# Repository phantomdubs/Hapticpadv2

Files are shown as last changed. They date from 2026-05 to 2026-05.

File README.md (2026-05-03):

# CNCDan - Haptic Pad
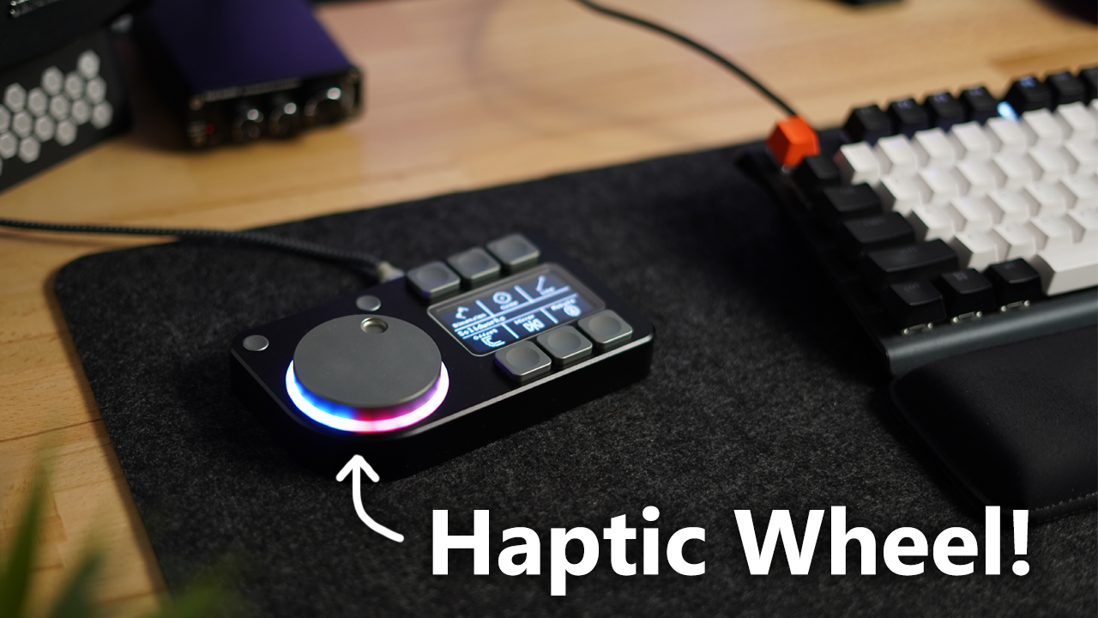
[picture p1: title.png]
Haptic Pad


A 6 button macropad with a display for button labels and a mouse knob with haptic feedback!

[Project Video Link](https://youtu.be/bNUKRJQjuvQ)

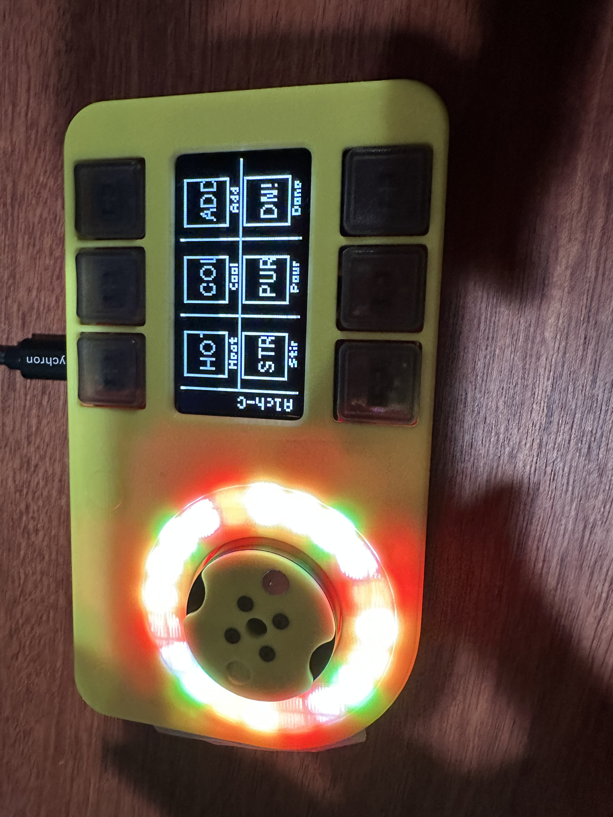
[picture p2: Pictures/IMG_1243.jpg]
Haptic Pad v2.0 Haptic Pad v2.0 Powered On


#### 🆕 New Advanced Features (v2.0)

*   **USB Drive Mode**: Edit your SD card files directly from your PC! Hold **Button 5 (Center Bottom)** while plugging in the USB cable to mount the internal SD card as a flash drive. 
*   **Reboot Shortcut**: While in USB Drive Mode, simply press **Button 1 (Top Left)** to exit and reboot the pad back into normal mode.
*   **Smart Sleep Mode**: To preserve the OLED display and save power, the pad automatically enters sleep mode after 5 minutes of inactivity. Press any button to wake it up.
*   **Per-Profile LEDs**: LED colors and modes are now tied to your active profile. Your pad can now automatically change its "look" whenever you switch between apps or games.
*   **Enhanced UI Layout**: The screen layout has been redesigned for better legibility. The profile name has been moved from the center to the edge of the screen, freeing up space for **larger 24x24 pixel icons** (upgraded from 16x16). 
*   **Diagnostic Tools**: Includes a `HardwareTester.uf2` file to quickly verify your wiring and motor directions before loading the main firmware.
*   **Custom Icon Support**: New Python scripts provided in the repository allow you to convert your own images into the exact bitmap format required for the OLED display. (**Note**: These scripts are intended as examples for icon creation and are not full-featured tools).

#### 🛠️ Design Improvements (v2.0)

The 3D files in this repository have been updated with several quality-of-life improvements:
*   **Choc Keycap Support**: The housing now features updated square keycap holes designed to fit standard **Kailh Choc low-profile keycaps** (available on Amazon/AliExpress) instead of being limited to custom 3D printed ones.
*   **Pico Button Access**: The bottom plate now includes two access holes so you can press the physical **Boot** and **Reset** buttons on the RP2040-Plus board without disassembling the case.
*   **Better Magnet Fit**: Magnet pockets on the knob and the knob interface plate have been slightly enlarged for a much better "press-fit" experience.

> [!IMPORTANT]
> **Assembly Note**: If you are using standard Choc keycaps, the **bottom-center keycap** must be trimmed down on its underside. This is necessary to prevent it from interfering with or damaging the LCD screen's ribbon cable during use.

#### 💡 Technical Notes & Troubleshooting

*   **Display Stability**: It is highly recommended to install the **10nF capacitor** (C1) on the controller board. This was optional in earlier versions but has been found necessary to reduce noise and prevent display flickering.
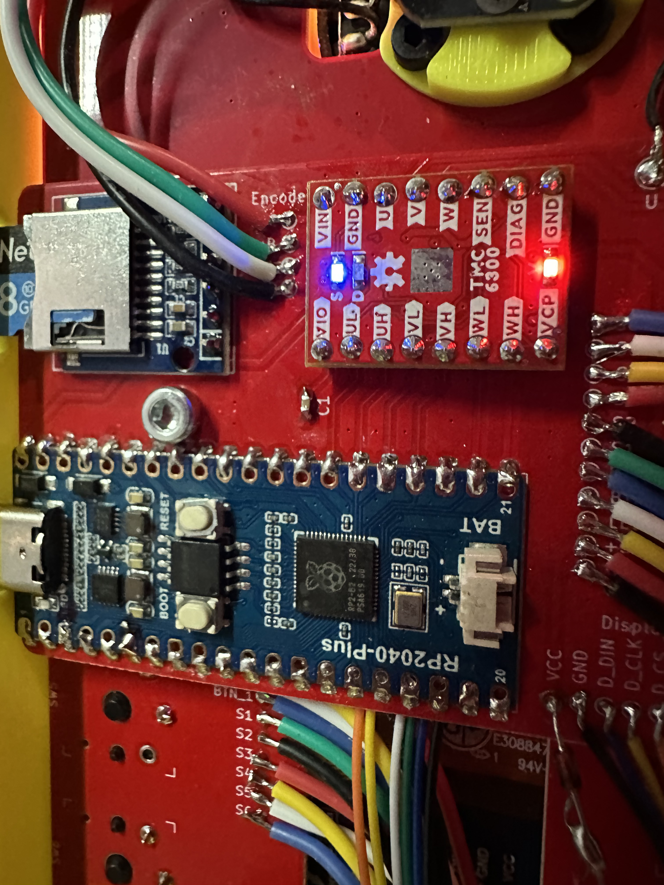
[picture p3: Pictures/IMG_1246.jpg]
Capacitor C1 Location Capacitor C1 on RP2040-Plus
    
*   **Voltage Logic Fix**: While the OLED display is rated for 5V, it can behave erratically when receiving 3.3V logic signals from the Pico. To fix this, **add a diode inline** with the 5V power supply to the display. This drops the voltage to ~4V, allowing the 3.3V logic signals to communicate reliably with the display.
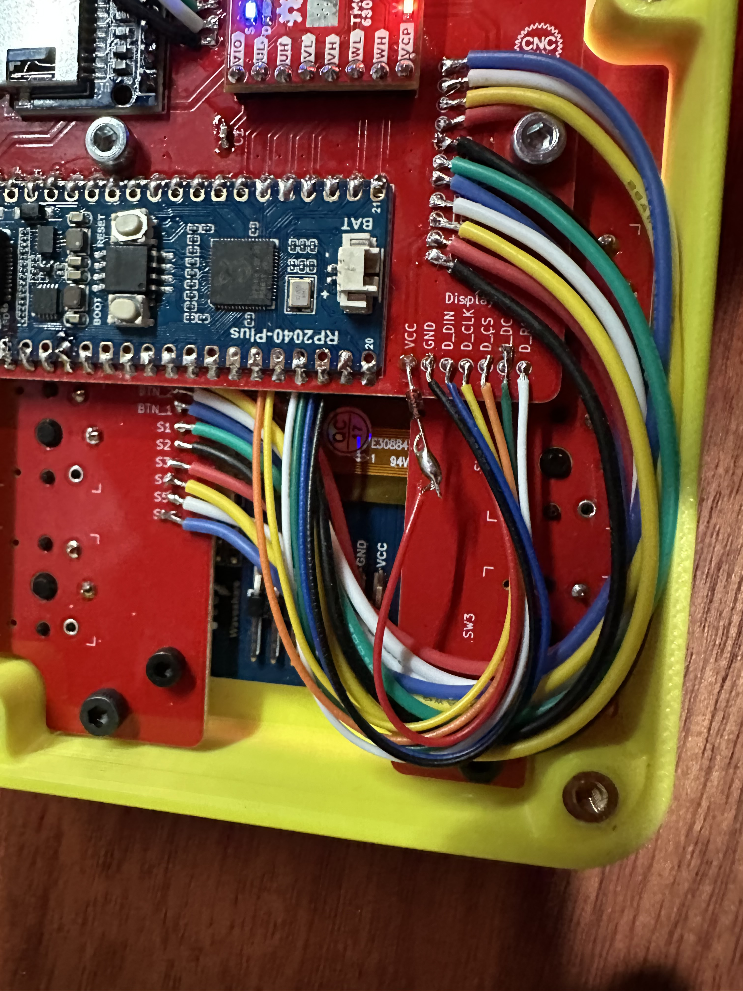
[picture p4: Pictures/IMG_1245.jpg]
Inline Diode Fix Inline Diode for Voltage Drop
    
*   **Hardware Tester Bug**: When running the knob test in `HardwareTester.uf2`, the mode names displayed on the screen (Clicky, Twist, Momentum) may not match the actual haptic mode being tested. As long as you feel three distinct haptic behaviors as you cycle through, your motor and encoder are working correctly.

#### Bill of Materials

For a complete list of components and purchasing links, please refer to the **[Parts List.csv](Parts%20List.csv)** file included in the root of this repository.

#### Printing Instructions

#### - Printed version
Print all files in the **3D Files/STL's** folder. You will need:
*   6 of the keycap file (**Note**: Only required if you are NOT using the updated v2.0 housing).
*   Two of the Menu button file.
*   Two of the PCB spacer file.

#### - Machined Version
Print all files in the **3D Files/STL's** folder except: "Custom Keycap.STL", "Macro Pad - Printed Version.STL" and "Menu Button Printed.STL".
Get all of the .STEP files in the **3D Files/STEP** folder machined. Don't include the Macropad Assembly .STEP file from the main directory as it is a complete model of Macro Pad rather than an individual part.

---

### Software

> [!TIP]
> **Recommended First Step**: Flash the `HardwareTester.uf2` file found in the `HardwareTester` folder first. This allows you to verify all your buttons, the display, and the motor encoder are working correctly before loading the full MacroPad firmware.

#### Flashing the Firmware
If you don't wish to compile the code yourself, just copy the latest version of the `MacroPad_V2.0.uf2` file from the software folder and install it directly onto the memory of your Pico using the boot method shown in the video.

You will also need to have your SD card set up correctly in order to use the macro pad.
Copy the entire contents of the **Example SD Card** folder onto you SD card to begin with. This folder now includes **6 extensive example profiles** (`StarNavC`, `Mech-T`, `CybMix-M`, `Alch-C`, `Hack-T`, and `Race-M`) to help you get started.

### XML Config

In the `<Settings>` tag of the XML file you will find the P and I tuning values for the various wheel modes.

#### Per-Profile Settings
Unlike previous versions, the LED settings are now stored **inside each profile**. This allows you to have unique lighting for every application.

*   `<LED_Mode>`: Acceptable inputs are `Breath`, `Bands`, `Halo`, `Rainbow`, `Solid`, and `Off`.
*   `<LED_Primary>` & `<LED_Secondary>`: Colors formatted as R,G,B (0-255). 
*   `<LED_Brightness>`: Set the intensity (0-255).
*   `<WheelMode>`: `Clicky`, `Twist`, or `Momentum`.
*   `<WheelKey>`: Any key value from [keycode-visualizer](https://keycode-visualizer.netlify.app/) to be held while the wheel is moving.

#### Macro Buttons
Each profile contains 6 `<MacroButton>` tags:
```xml
<MacroButton>
    <Action>0,68</Action> <!-- Delay(ms), KeyCode -->
    <Action>0,0</Action>
    <Action>0,0</Action>
    <Label>Dimension</Label>
</MacroButton>
```
Each action has two values: the delay (in ms) followed by the keycode. Setting both to 0 skips the action.

---

### Hardware Assembly & PCB's

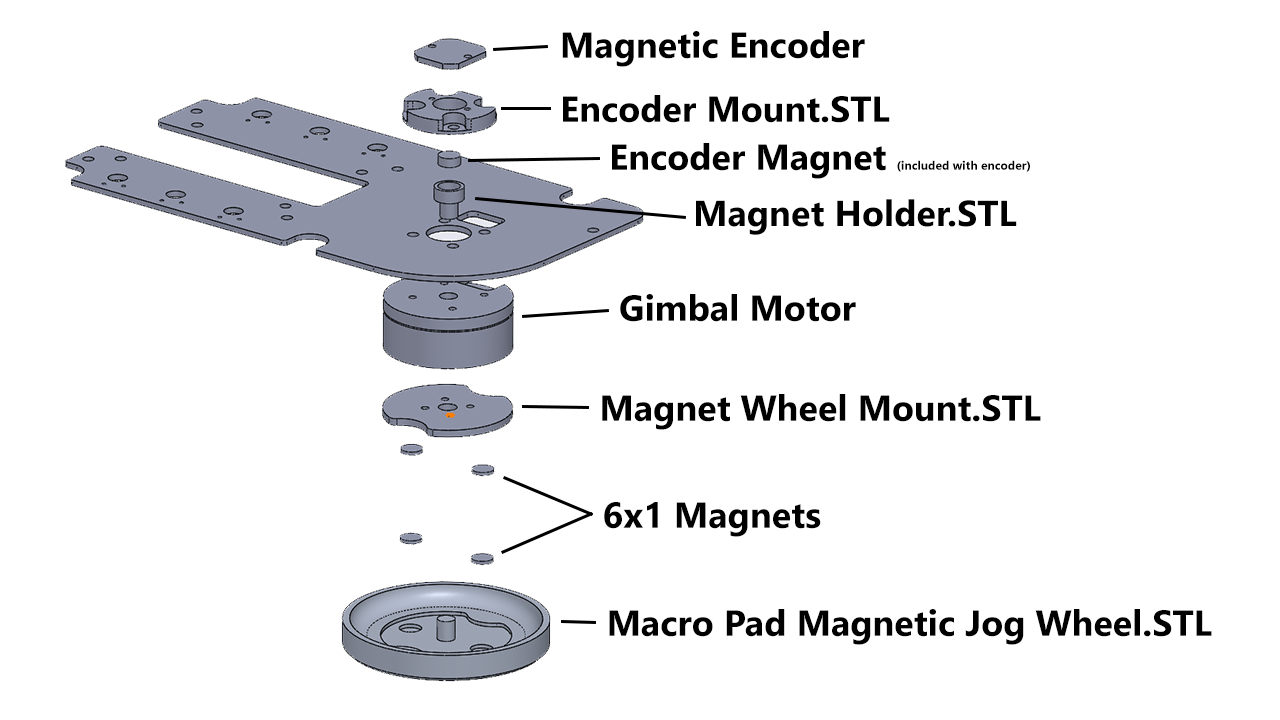
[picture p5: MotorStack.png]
Exploded Motor Assembly Motor Stack Assembly Diagram


*(See the original repository for detailed wiring diagrams and PCB assembly guides)*

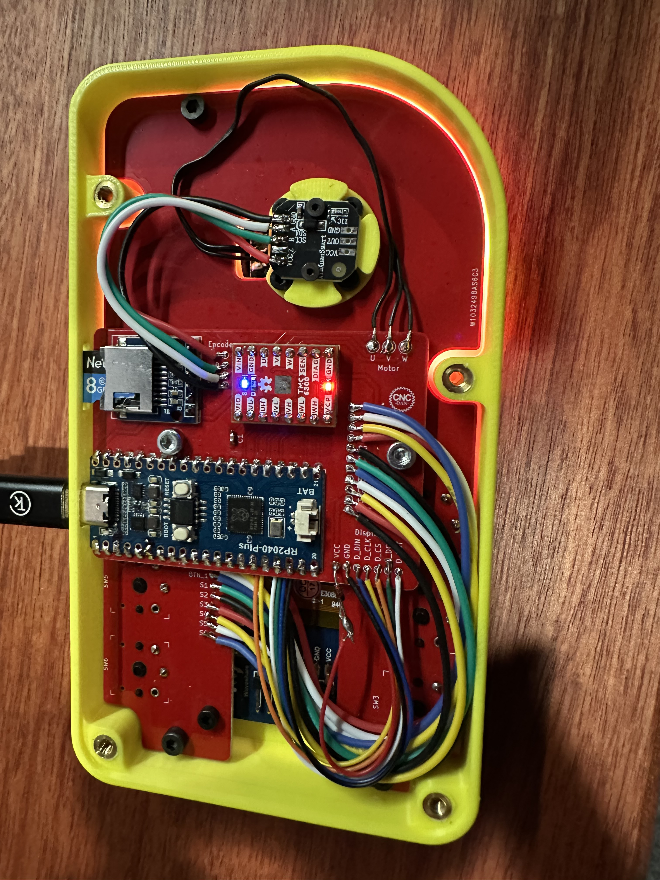
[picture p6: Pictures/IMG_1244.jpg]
Assembled Internal Wiring Internal Wiring View

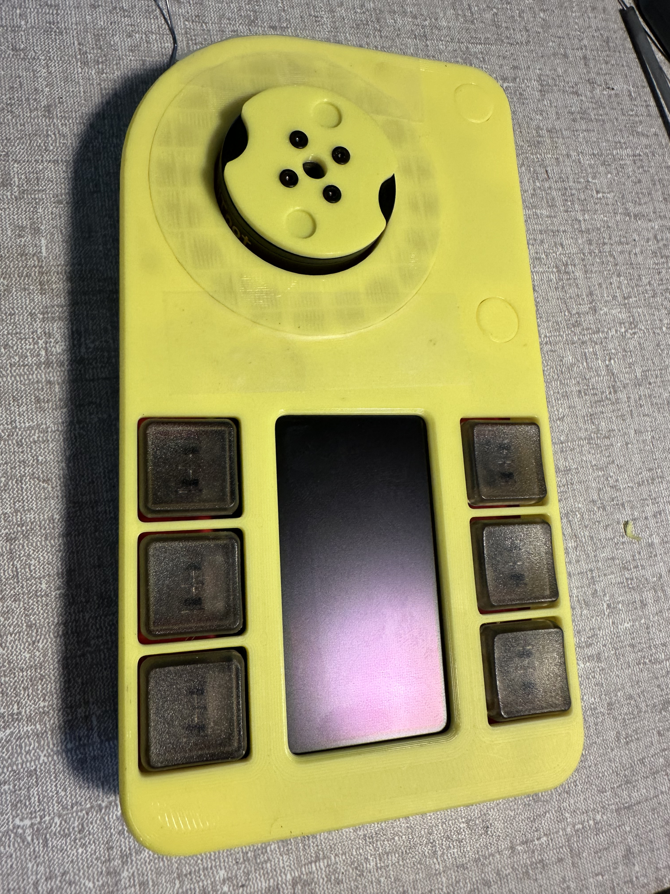
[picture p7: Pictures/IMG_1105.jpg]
Assembled Top View Haptic Pad Assembled (Top)


You will need to have both PCB's made to complete this project. Zip files for manufacturing can be found in `PCB's/MacroPad` and `PCB's/MacroPad Controller Board`.

**Controller Board**: The SD reader should be flat against the PCB. The motor controller gets installed on pin headers with the "bottom" face up. The Pico should be soldered directly with its USB port facing outwards.

**Main Board**: If including LEDs, install them first! Match the arrow rebate to the "1" pad. All "C" components are 0.1uF 0603 capacitors.

**Connecting**: Boards are connected via direct wiring. Match the labels on both boards. The three motor wires connect to U, V, and W (order can be swapped if direction is wrong). Encoder connections are also labelled—only the four main pins are required.

> [!TIP]
> **Screw Installation Hack**: The original design calls for tapping the plastic for M2 screws. If you don't have an M2 tap, you can simply use a hot soldering iron to carefully press the screws into the pre-sized holes in the plastic. This melts the plastic slightly around the threads, creating a very secure hold once cooled.

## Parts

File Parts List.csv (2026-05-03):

Part Name | PN (if available) | QTY Reqd | price | qty designator | link
128x64 OLED Display | sku: 25742 | 1 | $12.99 | ea | https://www.waveshare.com/2.42inch-oled-module.htm
Magnetic Encoder Board (mt6701) | MT6701 | 1 | $4.12 | ea | https://www.aliexpress.com/item/1005007469177411.html
2804 100kv Brushless Gimbal Motor | 2804 100kv | 1 | $23.44 | ea | https://www.aliexpress.us/item/3256801872144034.html?curPageLogUid=ZmV0swoLEkdW
Kailh Low Profile Switches | 1350 | 1 | $12.20 | 30 pack | https://www.aliexpress.us/item/3256804880270570.html?gatewayAdapt=glo2usa4itemAdapt
RP2040-Plus Board (without header) | RP2040-Plus-16MB | 1 | $6.99 | ea | https://www.waveshare.com/rp2040-plus.htm?sku=23503
TMC6300 Motor Driver Board | TMC6300 | 1 | $17.95 | ea | https://www.sparkfun.com/sparkfun-brushless-motor-driver-3-phase-tmc6300.html
Micro SD Module-3.3V SPI TF Storage |  | 1 | $0.99 | 10 pk | https://www.aliexpress.us/item/3256810401669594.html?gatewayAdapt=glo2usa4itemAdapt
6x1mm Magnets |  | 1 | $2.53 | 50 pk | https://www.aliexpress.us/item/3256809708457389.html?gatewayAdapt=glo2usa4itemAdapt
Tactile Buttons | EVQ-Q2B03W | 1 | $2.26 | 10 pk | https://www.digikey.com/en/products/detail/panasonic-electronic-components/EVQ-Q2B03W/762882
Alternate Tactile Button | Order 3.1 height | 1 | 3.20 | 30 pk | https://www.aliexpress.us/item/3256808139893877.html
WS2811 LED's | WS2811 | 1 | $10.08 | 200 pk | https://www.aliexpress.us/item/2251832590417125.html?gatewayAdapt=glo2usa4itemAdapt
0.1uF (100nF) 0603 Capacitors |  | 1 | $1.52 | 100 pk | https://www.aliexpress.us/item/2251832780211793.html?gatewayAdapt=glo2usa4itemAdapt
Large PCB |  | 1 | $29.35 | 5 pk | Pcbway
Small PCB |  | 1 | $5.00 | 5 pk | pcbway
M3x5x5 Threaded Inserts | 94180A331 | 2 | $7.27 | pk 25 | McMaster carr
M3x6 SHCS | 91290A111 | 1 | $11.59 | pk 100 | McMaster carr
M3x10 SHCS | 95263A134 | 1 | $8.55 | pk 50 | McMaster carr
M2.5x4 SHCS | 91290A099 | 1 | $12.44 | pk 50 | McMaster carr
M3x6 CSK | 91294A126 | 1 | $5.45 | pk 100 | McMaster carr
Low profile keycaps |  | 1 | 13.99 | Pk 20 | https://www.amazon.com/dp/B0FK283QCB?th=1
M2-.04x6mm fhshcs |  | 1 | 6.79 | Pk 50 | https://www.amazon.com/dp/B0CQ1KS9NJ?th=1
Switching Signal Diode 200 mA 100 V Axial 100 Volt | 1N4148 DO-35 | 1 | 3.79 | Pk 20 | https://www.amazon.com/dp/B0DS1JLQ1X?th=1
Assorted Capacitors (to get 10nF) |  | 1 | 7.98 | Multi pack | https://www.amazon.com/dp/B06XDG3WQX?

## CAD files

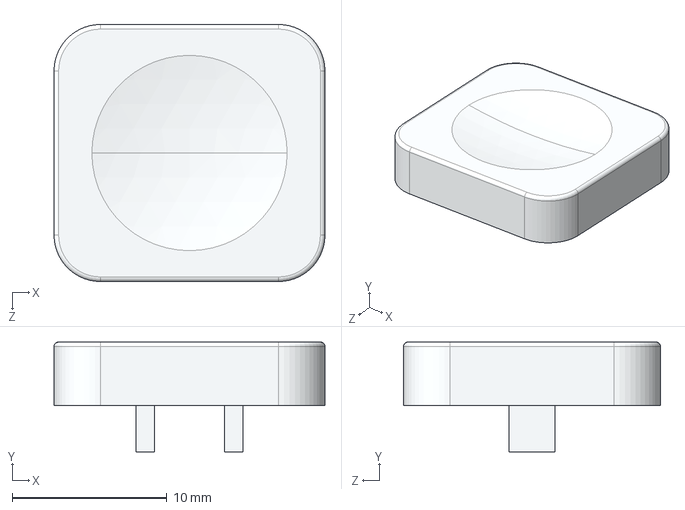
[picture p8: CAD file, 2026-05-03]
3D Files/STEP/Custom Keycap - Machined.STEP
17.5 x 7.10 x 16.6 mm

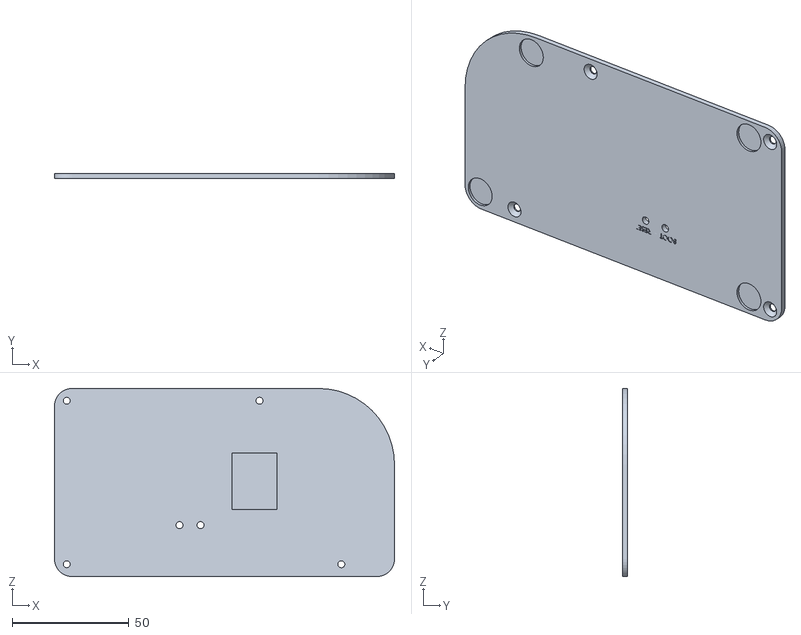
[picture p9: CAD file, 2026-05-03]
3D Files/STL's/Macropad Bottom Cover WITH reset and boot HOLES.STL
145.5 x 2.00 x 80.5

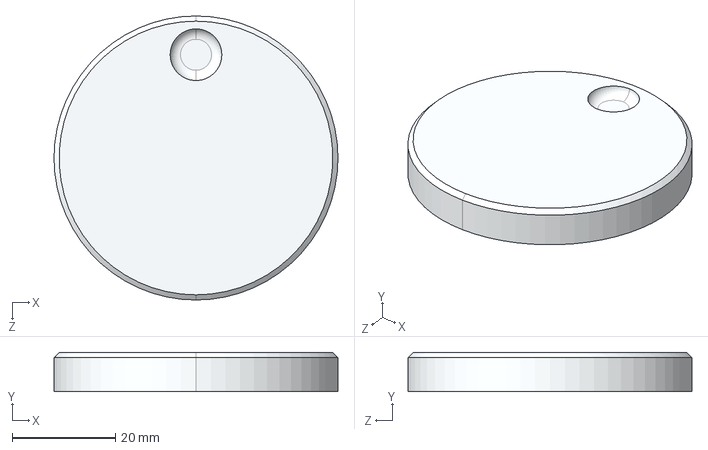
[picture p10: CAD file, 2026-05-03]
3D Files/STEP/Macro Pad Jog Wheel Machined.STEP
55.0 x 7.60 x 55.0 mm

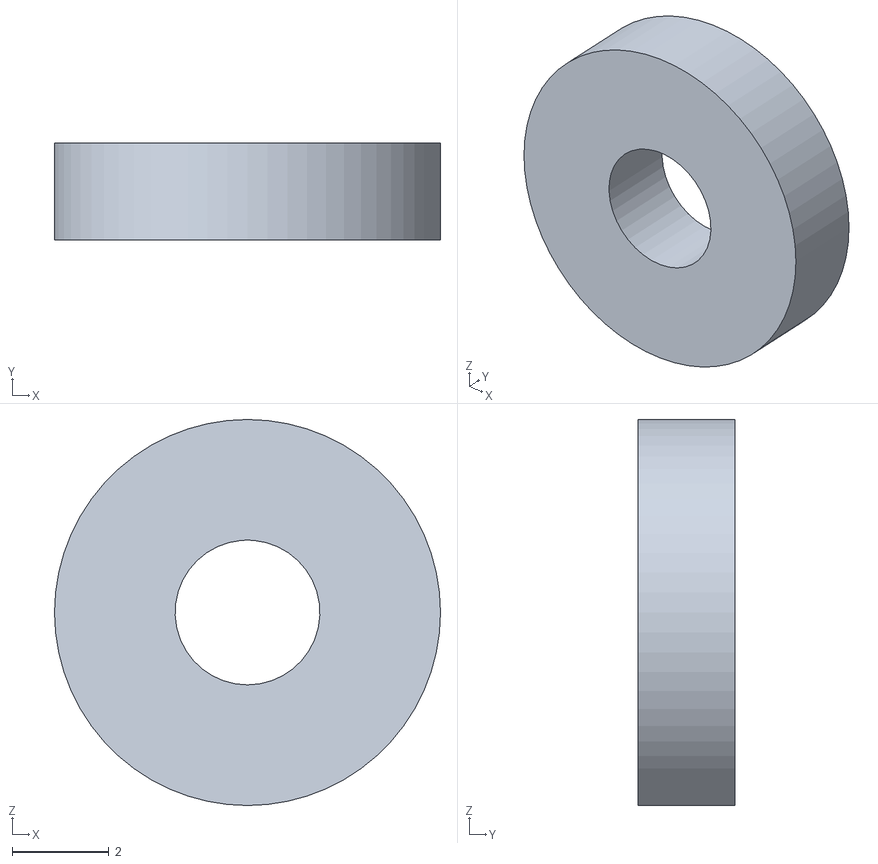
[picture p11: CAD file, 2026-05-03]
3D Files/STL's/PCB Spacer.STL
8.00 x 2.00 x 8.00

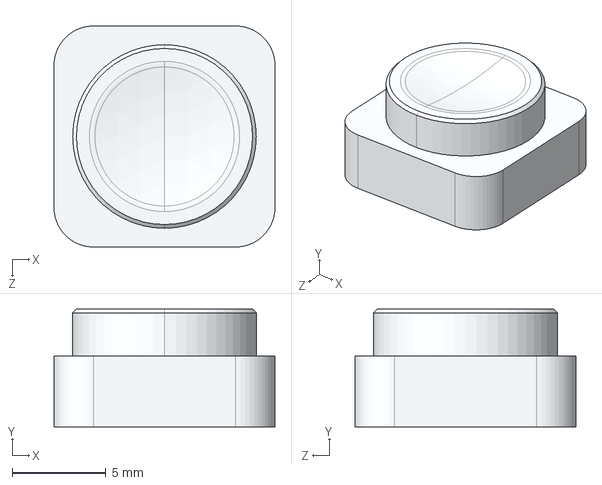
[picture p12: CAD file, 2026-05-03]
3D Files/STEP/Menu Button - Machined.STEP
11.8 x 6.30 x 11.8 mm

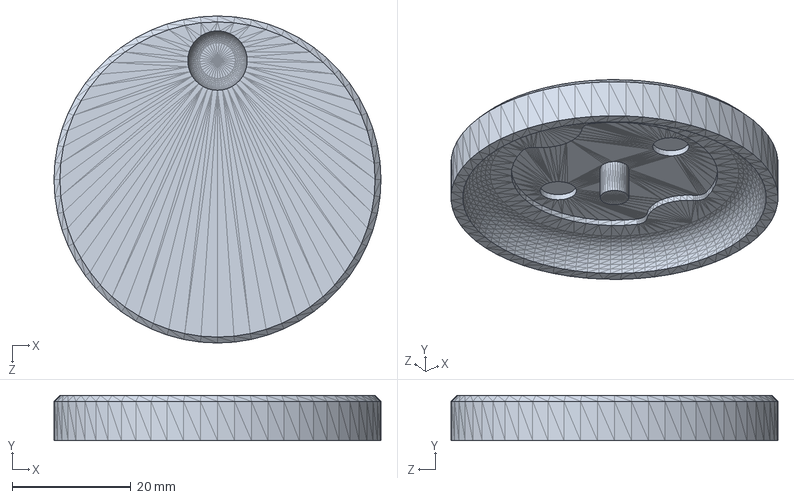
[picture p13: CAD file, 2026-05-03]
3D Files/STL's/Macro Pad Magnetic Jog Wheel 4-24-26.SLDPRT
55.0 x 7.60 x 55.0 mm

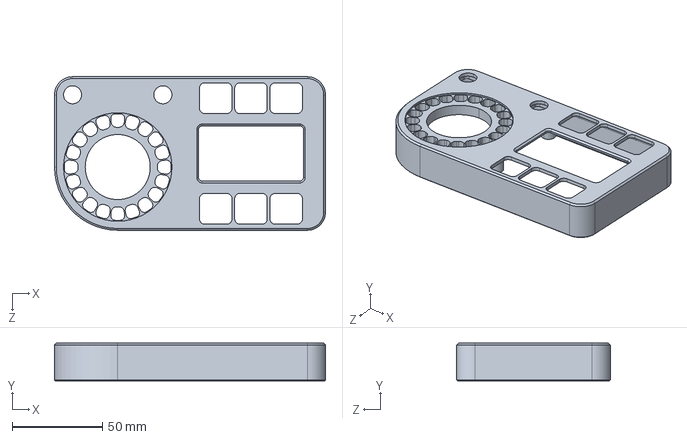
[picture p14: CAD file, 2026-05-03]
3D Files/STEP/Macro Pad Machined.STEP
150.0 x 21.0 x 85.0 mm

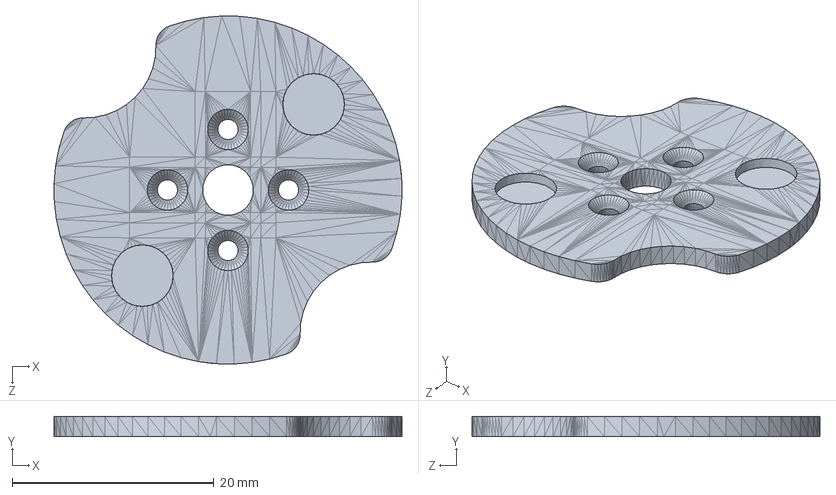
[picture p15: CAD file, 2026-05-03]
3D Files/STL's/Magnet Wheel Mount 4-24-26.SLDPRT
34.5 x 2.00 x 34.5 mm

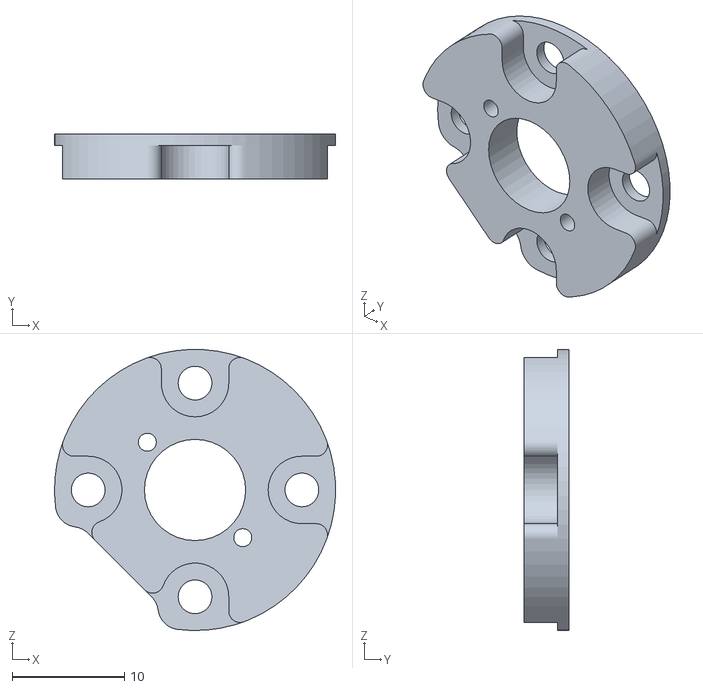
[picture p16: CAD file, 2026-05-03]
3D Files/STL's/Encoder Mount.STL
25.0 x 4.00 x 25.0

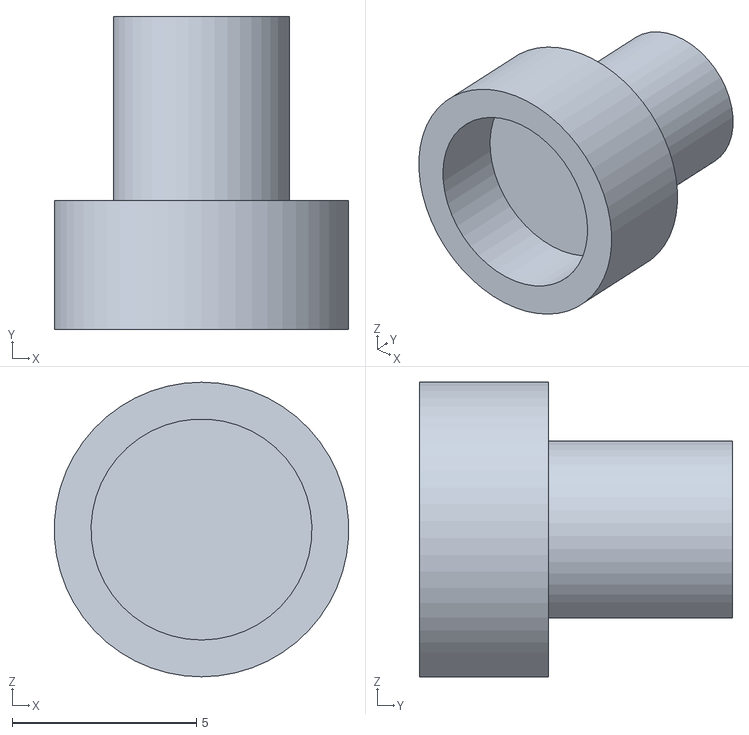
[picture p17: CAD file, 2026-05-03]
3D Files/STL's/Magnet Holder.STL
7.99 x 8.50 x 8.00

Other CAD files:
3D Files/STL's/Menu Button Printed.STL
3D Files/STL's/Macro Pad Magnetic Jog Wheel enlarged magnet 4-24-26.STL
3D Files/STL's/Custom Keycap.STL
3D Files/STL's/Macropad Bottom Cover.STL
3D Files/STL's/Magnet Wheel Mount.STL
3D Files/STL's/Macro Pad - Purchased Keycaps Revision Printed Version.STL
3D Files/STL's/Macro Pad - Printed Version.SLDPRT
3D Files/STL's/Macro Pad Magnetic Jog Wheel.STL
3D Files/STL's/LED Diffuser Ring.STL
3D Files/STL's/Macro Pad - Printed Version.STL
3D Files/STL's/Magnet Wheel Mount enlarged magnet 4-24-26.STL

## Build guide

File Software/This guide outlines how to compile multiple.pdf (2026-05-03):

This guide outlines how to compile multiple .ino files into a single .uf2 binary using the Arduino IDE. This process is common for modern microcontrollers like the Raspberry Pi Pico (RP2040) or ESP32-S2/S3.

Phase 1: Preparation & Organization
The Arduino IDE treats multiple files as a single project "sketch".
1. | 1. | Folder Setup: Place all six .ino files in a single folder. The folder name
must match the name of the main .ino file.
2. | 2. | Tab Order: Open the main .ino file. The other files will automatically
appear as tabs at the top.
- | o | Logic: The IDE concatenates (merges) these tabs into one large file
behind the scenes.
- | o | Sequence: It starts with the main file and then appends the others
in alphabetical order.
- | o | Tip: To control the merge order, rename tabs with a numeric prefix
(e.g., 10_Global.ino, 20_Setup.ino).

Phase 2: Compiling to Binary
Standard "Uploading" via the arrow button often bypasses the creation of a permanent file you can save. To get a file you can drag-and-drop, use the Export feature.
1. | 1. | Select Board: Go to Tools > Board and select your specific device.
2. | 2. | Verify Code: Click the Checkmark (Verify) icon to ensure no errors exist
in any tab.
3. | 3. | Export: Select Sketch > Export Compiled Binary.
- | o | This creates a subfolder in your project directory (usually called
build).
- | o | Depending on your board, this folder will contain .bin, .elf,
or .hex files.

NEW NOTE: Use save as function to start on a new revision and it will create the necessary adjustments

NEW NOTE: Use save as function to start on a new revision and it will create the necessary adjustmentsNOTES: after exporting it creates the build folder which has some subfolders and includes the UF2 file that is uploaded to the device. If you want to make a modification you need to dump everything into a new base folder or rename the existing build folder so it doesn’t get overwritten

Phase 3: Converting to UF2
A .uf2 file is specifically designed for "USB Flashing." Not all board packages generate this automatically.
Option A: Automatic Generation (Easiest)
Many modern board packages (like the Raspberry Pi Pico Mbed or Earle Philhower cores) automatically create a .uf2 file in the build folder alongside the other binaries when you click "Export Compiled Binary".
Option B: Using a Converter Tool
If the IDE only gives you a .bin or .hex file, you need a utility to convert it.
- | • | Utility Needed: uf2conv.py (a Python script provided by Microsoft/
Adafruit).
- | • | Step-by-Step:
1. | 1. | Install Python 3 on your computer.
2. | 2. | Open a Terminal or Command Prompt in the folder containing
your binary.
3. | 3. | Run the command:
python uf2conv.py firmware.bin -c -f [FamilyID]
(Replace firmware.bin with your file name. The "FamilyID" for RP2040 is
0xe48bff57).

Phase 4: Flashing the Device
1. | 1. | Enter Bootloader Mode: Plug in your device while holding its BOOT or
RESET button.
2. | 2. | Mount Drive: A new drive will appear on your computer (e.g., RPI-RP2
or CPLAYBOOT).
3. | 3. | Deploy: Drag your .uf2 file and drop it onto that drive.
4. | 4. | Auto-Run: The drive will disappear, and the device will reboot
automatically with your new code.
Summary Checklist
- | • | Software: Arduino IDE.
- | • | Utility: Python 3 (for manual conversion).
- | • | Key Command: Sketch > Export Compiled Binary.
- | • | File Location: Found via Sketch > Show Sketch Folder.

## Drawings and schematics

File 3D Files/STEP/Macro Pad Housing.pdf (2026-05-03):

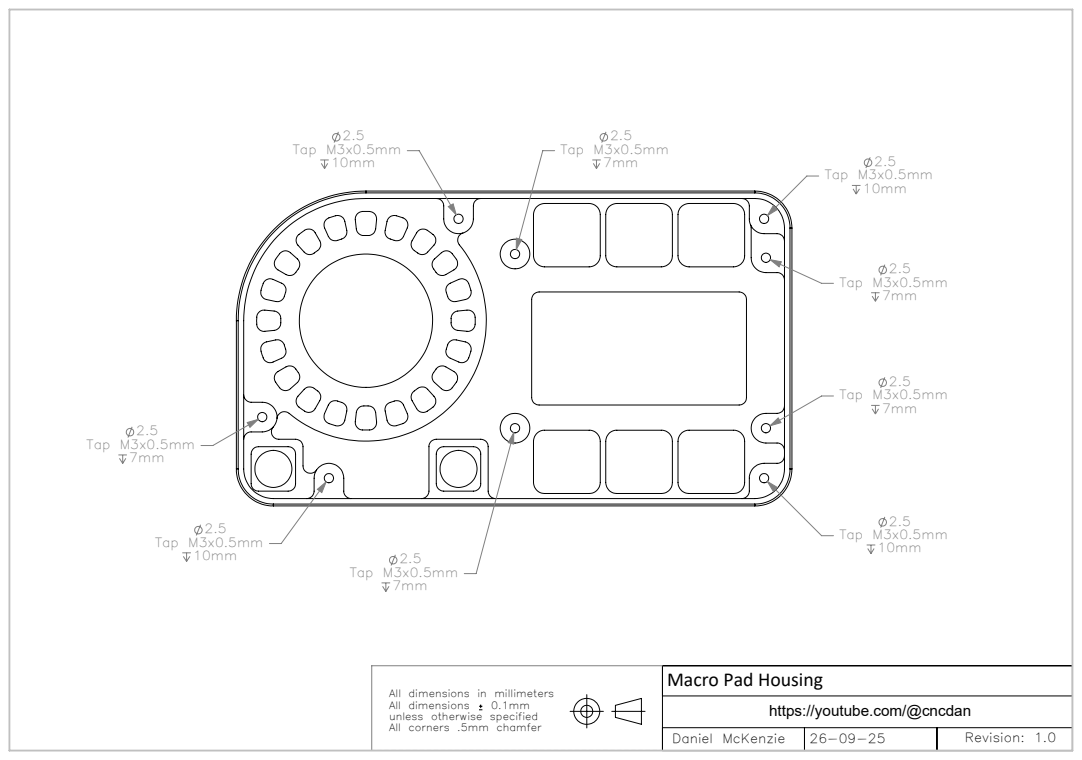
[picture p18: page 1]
Tap M3x0.5mm; Daniel McKenzie; Revision: 1.0; All dimensions

Macro Pad Housing

All dimensions in millimeters
unless otherwise specified
All corners .5mm chamfer

https://youtube.com/@cncdan

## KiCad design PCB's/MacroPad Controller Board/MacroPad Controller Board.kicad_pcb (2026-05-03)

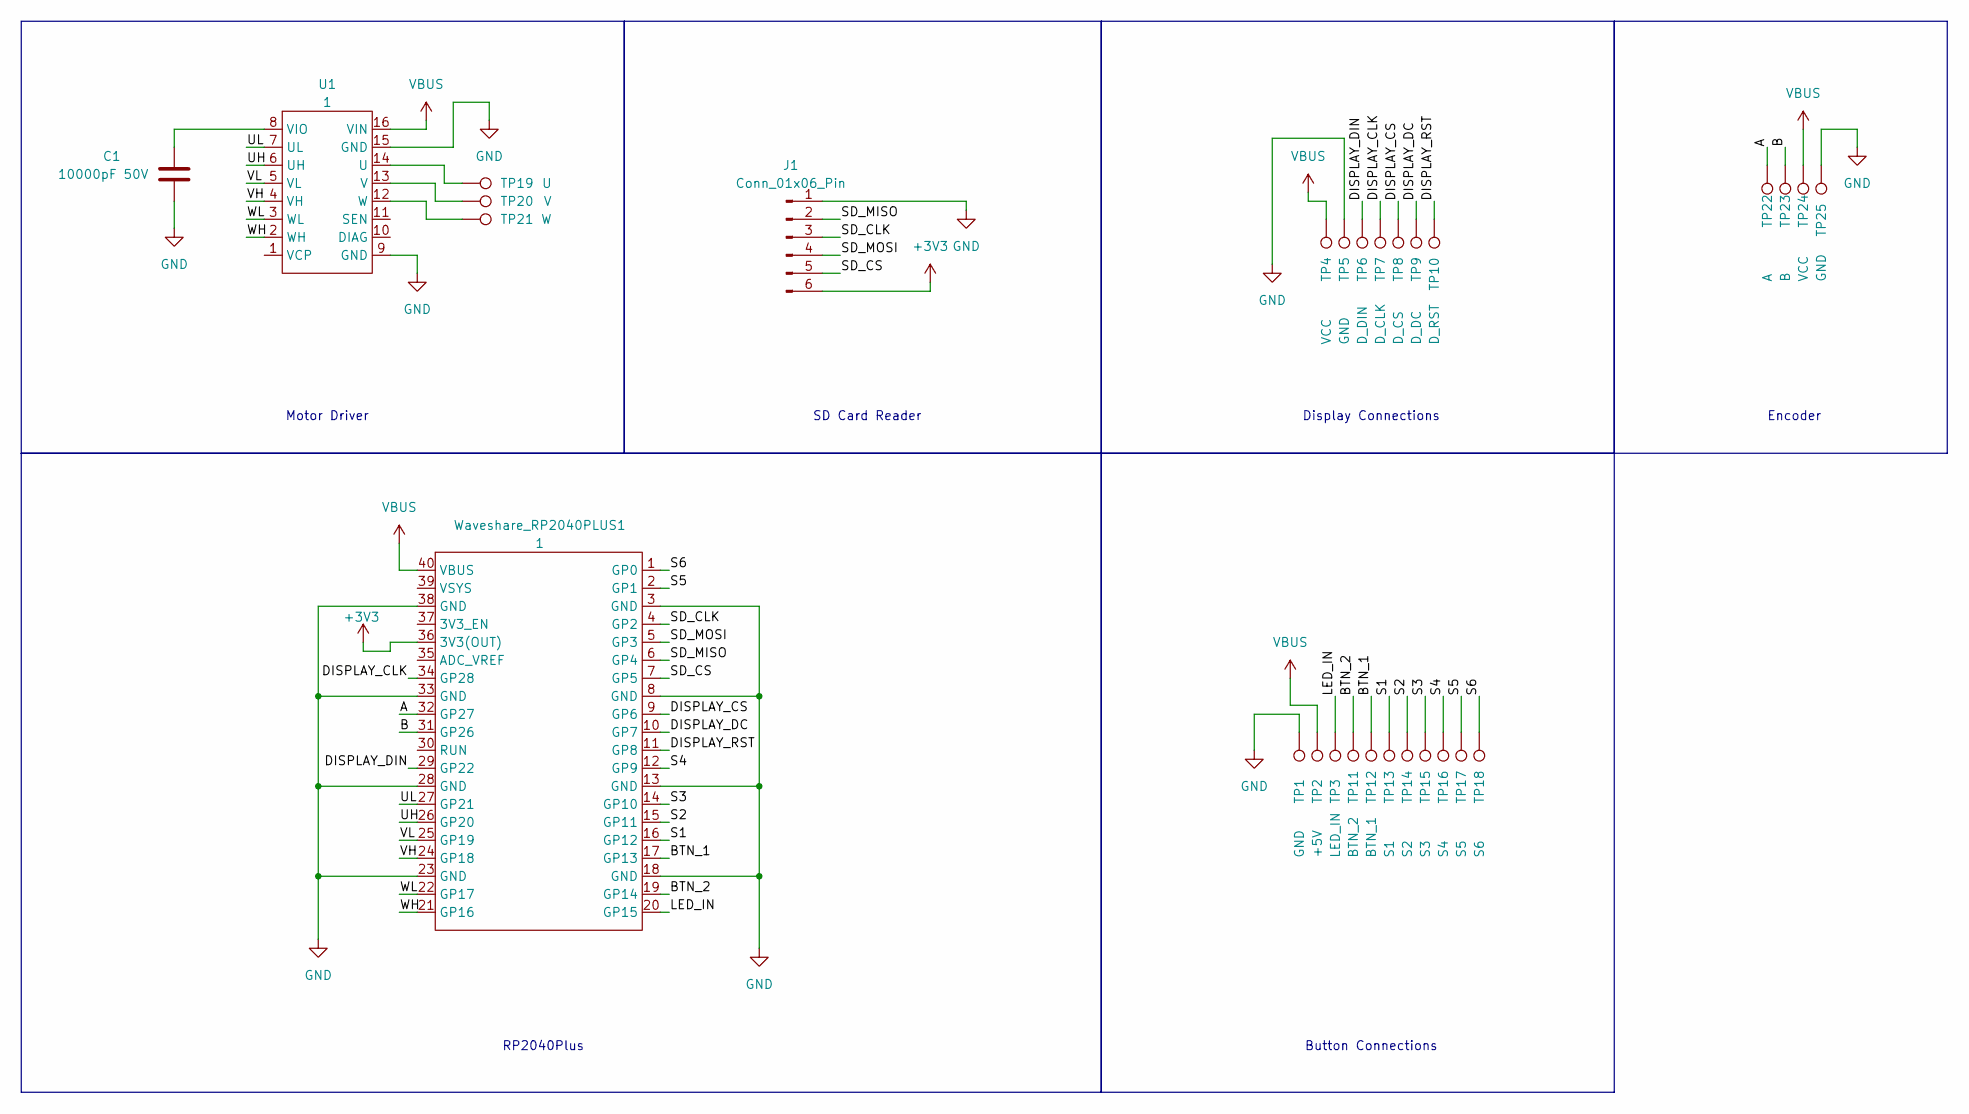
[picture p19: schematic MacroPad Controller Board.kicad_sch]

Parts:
C1: 10000pF 50V; C_0603_1608Metric_Pad1.08x0.95mm_HandSolder
J1: Conn_01x06_Pin; PinHeader_1x06_P2.54mm_Vertical
TP1, TP5, TP25: GND; TestPoint_THTPad_D1.0mm_Drill0.5mm
TP2: +5V; TestPoint_THTPad_D1.0mm_Drill0.5mm
TP3: LED_IN; TestPoint_THTPad_D1.0mm_Drill0.5mm
TP4, TP24: VCC; TestPoint_THTPad_D1.0mm_Drill0.5mm
TP6: D_DIN; TestPoint_THTPad_D1.0mm_Drill0.5mm
TP7: D_CLK; TestPoint_THTPad_D1.0mm_Drill0.5mm
TP8: D_CS; TestPoint_THTPad_D1.0mm_Drill0.5mm
TP9: D_DC; TestPoint_THTPad_D1.0mm_Drill0.5mm
TP10: D_RST; TestPoint_THTPad_D1.0mm_Drill0.5mm
TP11: BTN_2; TestPoint_THTPad_D1.0mm_Drill0.5mm
TP12: BTN_1; TestPoint_THTPad_D1.0mm_Drill0.5mm
TP13: S1; TestPoint_THTPad_D1.0mm_Drill0.5mm
TP14: S2; TestPoint_THTPad_D1.0mm_Drill0.5mm
TP15: S3; TestPoint_THTPad_D1.0mm_Drill0.5mm
TP16: S4; TestPoint_THTPad_D1.0mm_Drill0.5mm
TP17: S5; TestPoint_THTPad_D1.0mm_Drill0.5mm
TP18: S6; TestPoint_THTPad_D1.0mm_Drill0.5mm
TP19: U; TestPoint_THTPad_D2.0mm_Drill1.0mm
TP20: V; TestPoint_THTPad_D2.0mm_Drill1.0mm
TP21: W; TestPoint_THTPad_D2.0mm_Drill1.0mm
TP22: A; TestPoint_THTPad_D1.0mm_Drill0.5mm
TP23: B; TestPoint_THTPad_D1.0mm_Drill0.5mm
U1: 1; Sparkfun_TMC6300
Waveshare_RP2040PLUS1: 1; RP2040PLUS_SMD

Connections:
+3V3: J1.6, Waveshare_RP2040PLUS1.36 (3V3(OUT)); also elsewhere on the board
/A: TP22.1, Waveshare_RP2040PLUS1.32 (GP27); also elsewhere on the board
/B: TP23.1, Waveshare_RP2040PLUS1.31 (GP26); also elsewhere on the board
/BTN_1: TP12.1, Waveshare_RP2040PLUS1.17 (GP13); also elsewhere on the board
/BTN_2: TP11.1, Waveshare_RP2040PLUS1.19 (GP14); also elsewhere on the board
/DISPLAY_CLK: TP7.1, Waveshare_RP2040PLUS1.34 (GP28); also elsewhere on the board
/DISPLAY_CS: TP8.1, Waveshare_RP2040PLUS1.9 (GP6); also elsewhere on the board
/DISPLAY_DC: TP9.1, Waveshare_RP2040PLUS1.10 (GP7); also elsewhere on the board
/DISPLAY_DIN: TP6.1, Waveshare_RP2040PLUS1.29 (GP22); also elsewhere on the board
/DISPLAY_RST: TP10.1, Waveshare_RP2040PLUS1.11 (GP8); also elsewhere on the board
/LED_IN: TP3.1, Waveshare_RP2040PLUS1.20 (GP15); also elsewhere on the board
/S1: TP13.1, Waveshare_RP2040PLUS1.16 (GP12); also elsewhere on the board
/S2: TP14.1, Waveshare_RP2040PLUS1.15 (GP11); also elsewhere on the board
/S3: TP15.1, Waveshare_RP2040PLUS1.14 (GP10); also elsewhere on the board
/S4: TP16.1, Waveshare_RP2040PLUS1.12 (GP9); also elsewhere on the board
/S5: TP17.1, Waveshare_RP2040PLUS1.2 (GP1); also elsewhere on the board
/S6: TP18.1, Waveshare_RP2040PLUS1.1 (GP0); also elsewhere on the board
/SD_CLK: J1.3, Waveshare_RP2040PLUS1.4 (GP2); also elsewhere on the board
/SD_CS: J1.5, Waveshare_RP2040PLUS1.7 (GP5); also elsewhere on the board
/SD_MISO: J1.2, Waveshare_RP2040PLUS1.6 (GP4); also elsewhere on the board
/SD_MOSI: J1.4, Waveshare_RP2040PLUS1.5 (GP3); also elsewhere on the board
/UH: U1.6 (UH), Waveshare_RP2040PLUS1.26 (GP20); also elsewhere on the board
/UL: U1.7 (UL), Waveshare_RP2040PLUS1.27 (GP21); also elsewhere on the board
/VH: U1.4 (VH), Waveshare_RP2040PLUS1.24 (GP18); also elsewhere on the board
/VL: U1.5 (VL), Waveshare_RP2040PLUS1.25 (GP19); also elsewhere on the board
/WH: U1.2 (WH), Waveshare_RP2040PLUS1.21 (GP16); also elsewhere on the board
/WL: U1.3 (WL), Waveshare_RP2040PLUS1.22 (GP17); also elsewhere on the board
GND: C1.2, J1.1, TP1.1, TP5.1, TP25.1, U1.9 (GND), U1.15 (GND), Waveshare_RP2040PLUS1.3 (GND), Waveshare_RP2040PLUS1.8 (GND), Waveshare_RP2040PLUS1.13 (GND), Waveshare_RP2040PLUS1.18 (GND), Waveshare_RP2040PLUS1.23 (GND), Waveshare_RP2040PLUS1.28 (GND), Waveshare_RP2040PLUS1.33 (GND), Waveshare_RP2040PLUS1.38 (GND); also elsewhere on the board
unnamed: TP19.1, U1.14 (U)
unnamed: TP20.1, U1.13 (V)
unnamed: C1.1, U1.8 (VIO)
unnamed: TP21.1, U1.12 (W)
VBUS: TP2.1, TP4.1, TP24.1, U1.16 (VIN), Waveshare_RP2040PLUS1.40 (VBUS); also elsewhere on the board

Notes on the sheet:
Motor Driver
SD Card Reader
RP2040Plus
Display Connections
Button Connections
Encoder

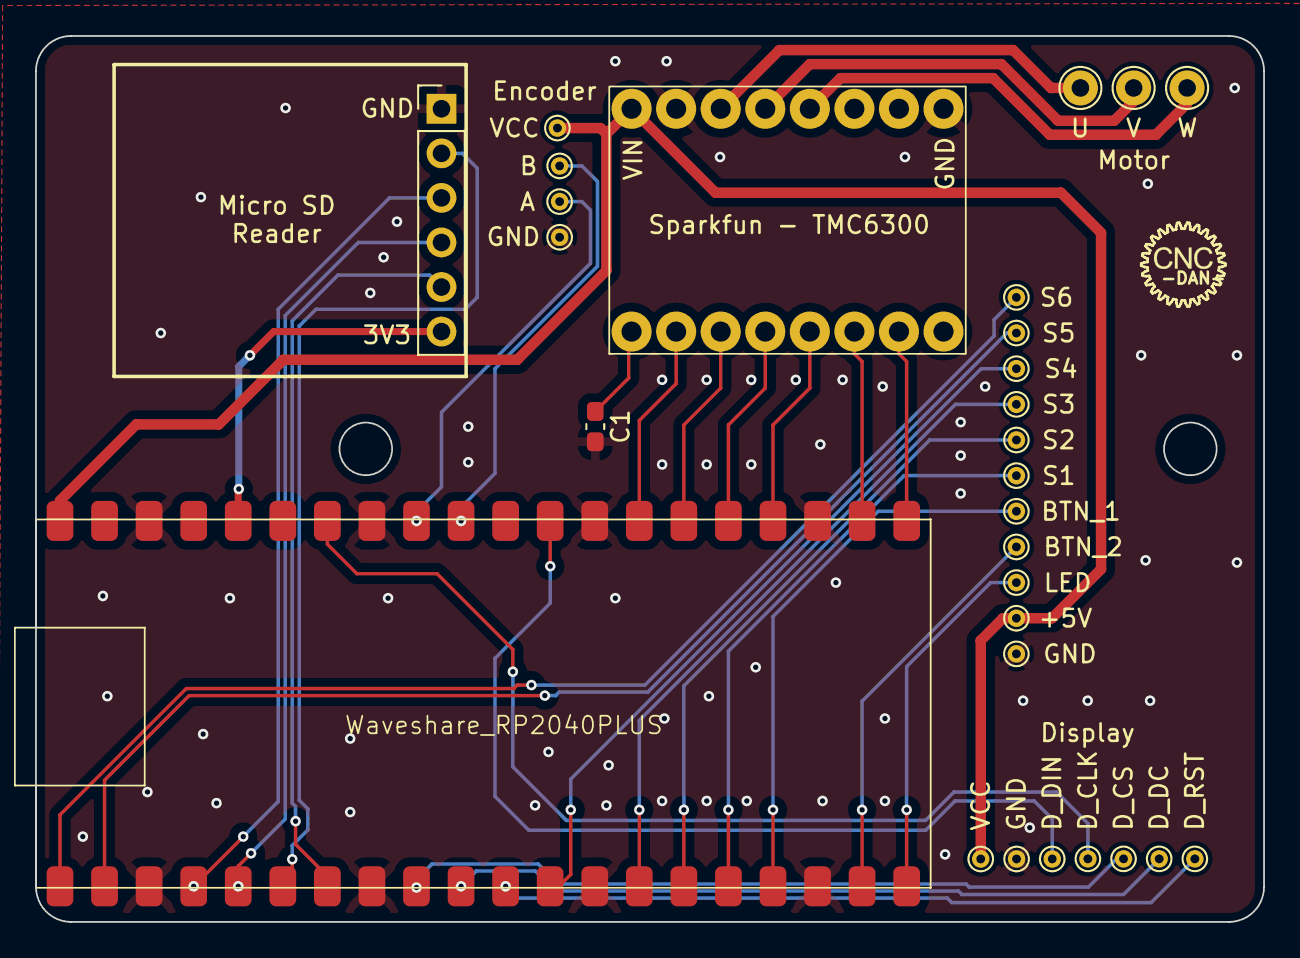
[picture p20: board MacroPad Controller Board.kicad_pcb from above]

Board: 2 copper layers, 70.0 x 50.5 mm, 29 parts (0 on the bottom side), 33 nets.

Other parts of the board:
Waveshare_RP2040PLUS: 1; RP2040PLUS_SMD

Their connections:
+3V3: Waveshare_RP2040PLUS.36 (3V3(OUT)); also elsewhere on the board
/A: Waveshare_RP2040PLUS.32 (GP27); also elsewhere on the board
/B: Waveshare_RP2040PLUS.31 (GP26); also elsewhere on the board
/BTN_1: Waveshare_RP2040PLUS.17 (GP13); also elsewhere on the board
/BTN_2: Waveshare_RP2040PLUS.19 (GP14); also elsewhere on the board
/DISPLAY_CLK: Waveshare_RP2040PLUS.34 (GP28); also elsewhere on the board
/DISPLAY_CS: Waveshare_RP2040PLUS.9 (GP6); also elsewhere on the board
/DISPLAY_DC: Waveshare_RP2040PLUS.10 (GP7); also elsewhere on the board
/DISPLAY_DIN: Waveshare_RP2040PLUS.29 (GP22); also elsewhere on the board
/DISPLAY_RST: Waveshare_RP2040PLUS.11 (GP8); also elsewhere on the board
/LED_IN: Waveshare_RP2040PLUS.20 (GP15); also elsewhere on the board
/S1: Waveshare_RP2040PLUS.16 (GP12); also elsewhere on the board
/S2: Waveshare_RP2040PLUS.15 (GP11); also elsewhere on the board
/S3: Waveshare_RP2040PLUS.14 (GP10); also elsewhere on the board
/S4: Waveshare_RP2040PLUS.12 (GP9); also elsewhere on the board
/S5: Waveshare_RP2040PLUS.2 (GP1); also elsewhere on the board
/S6: Waveshare_RP2040PLUS.1 (GP0); also elsewhere on the board
/SD_CLK: Waveshare_RP2040PLUS.4 (GP2); also elsewhere on the board
/SD_CS: Waveshare_RP2040PLUS.7 (GP5); also elsewhere on the board
/SD_MISO: Waveshare_RP2040PLUS.6 (GP4); also elsewhere on the board
/SD_MOSI: Waveshare_RP2040PLUS.5 (GP3); also elsewhere on the board
/UH: Waveshare_RP2040PLUS.26 (GP20); also elsewhere on the board
/UL: Waveshare_RP2040PLUS.27 (GP21); also elsewhere on the board
/VH: Waveshare_RP2040PLUS.24 (GP18); also elsewhere on the board
/VL: Waveshare_RP2040PLUS.25 (GP19); also elsewhere on the board
/WH: Waveshare_RP2040PLUS.21 (GP16); also elsewhere on the board
/WL: Waveshare_RP2040PLUS.22 (GP17); also elsewhere on the board
GND: Waveshare_RP2040PLUS.3 (GND), Waveshare_RP2040PLUS.8 (GND), Waveshare_RP2040PLUS.13 (GND), Waveshare_RP2040PLUS.18 (GND), Waveshare_RP2040PLUS.23 (GND), Waveshare_RP2040PLUS.28 (GND), Waveshare_RP2040PLUS.33 (GND), Waveshare_RP2040PLUS.38 (GND); also elsewhere on the board
VBUS: Waveshare_RP2040PLUS.40 (VBUS); also elsewhere on the board

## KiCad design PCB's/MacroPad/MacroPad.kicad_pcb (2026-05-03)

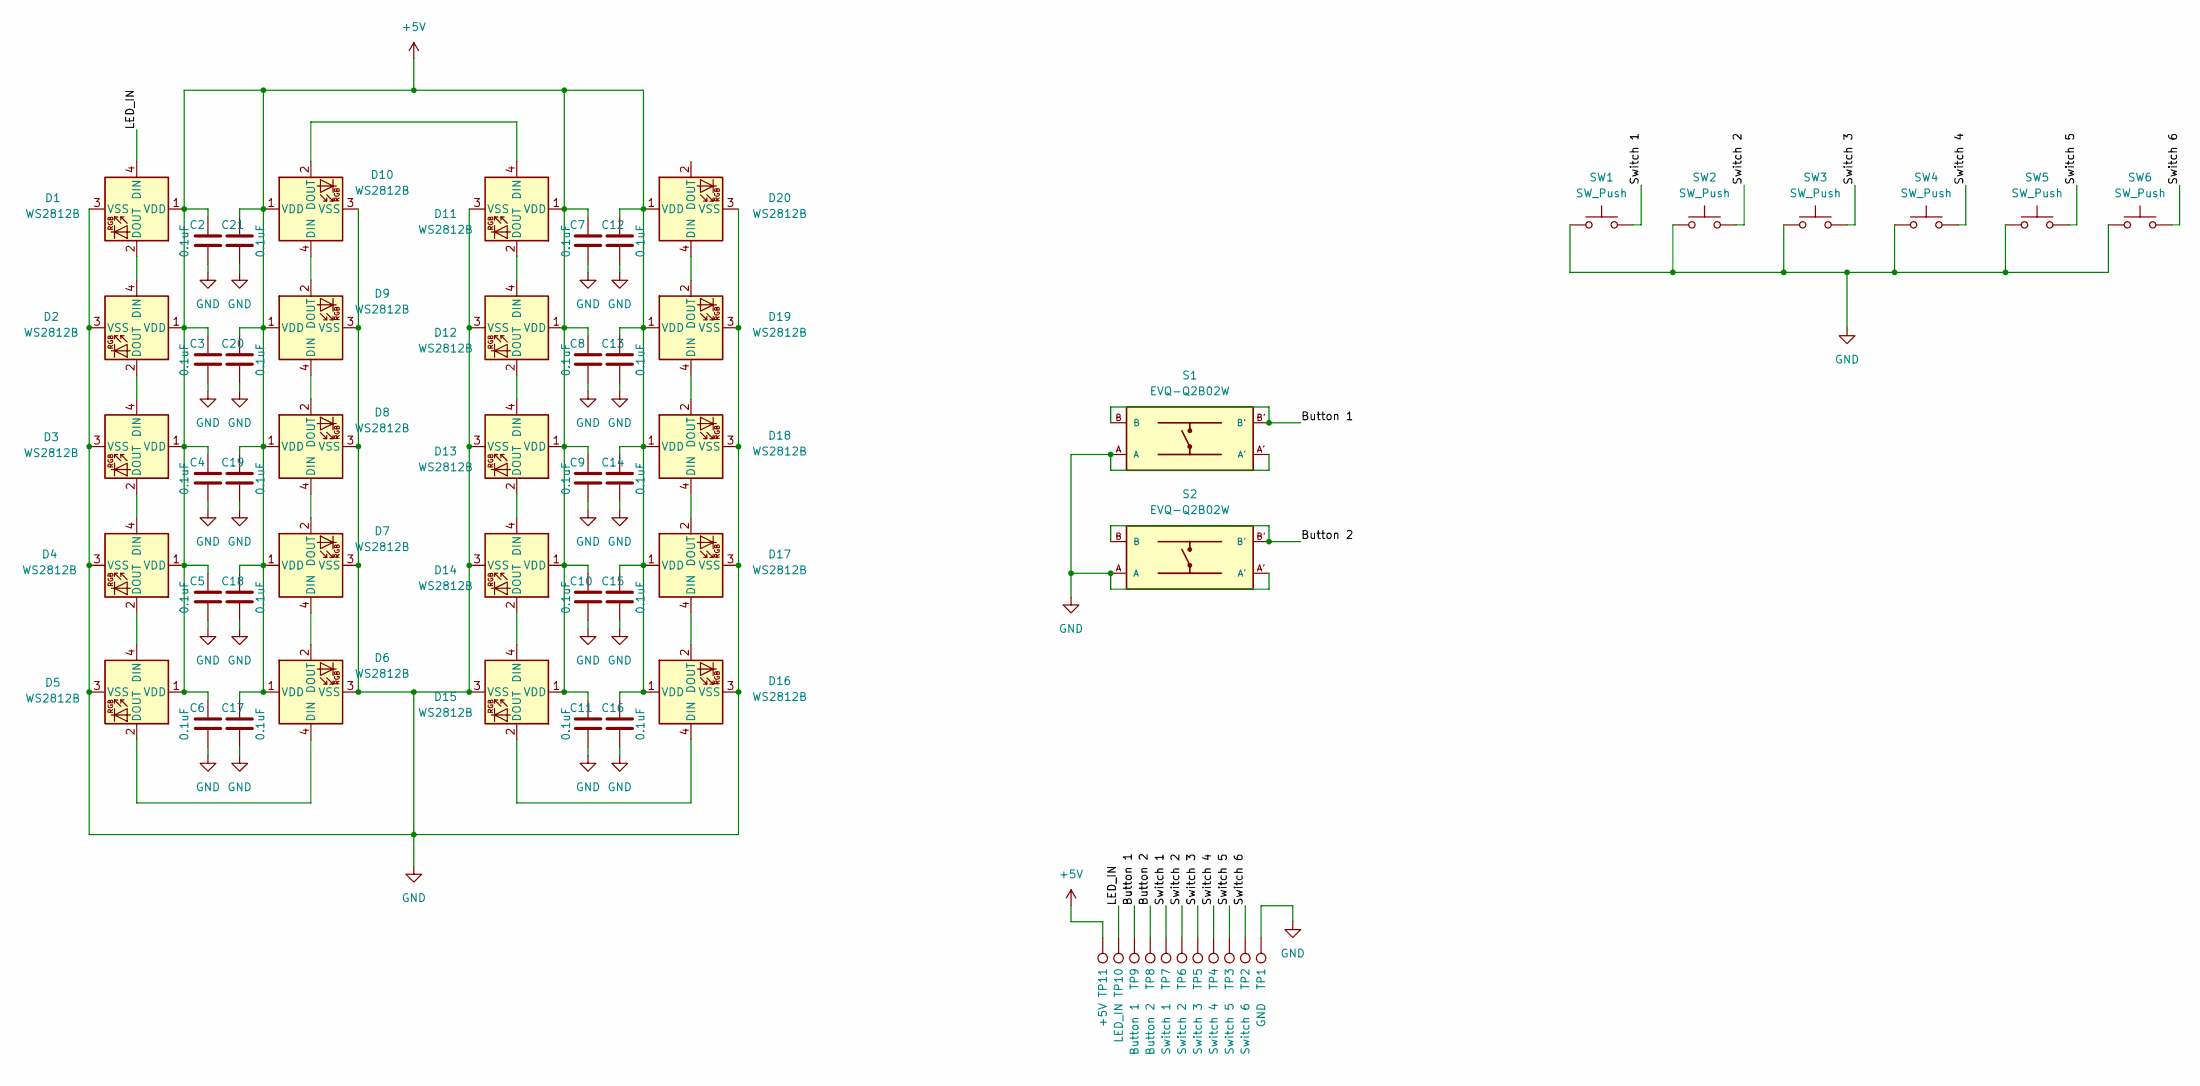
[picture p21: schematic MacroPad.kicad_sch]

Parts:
C2, C3, C4, C5, C6, C7, C8, C9, C10, C11, C12, C13, C14, C15, C16, C17, C18, C19, C20, C21: 0.1uF; C_0603_1608Metric
D1, D2, D3, D4, D5, D6, D7, D8, D9, D10, D11, D12, D13, D14, D15, D16, D17, D18, D19, D20: WS2812B; LED_WS2812B_PLCC4_5.0x5.0mm_P3.2mm
S1, S2: EVQ-Q2B02W; SW_EVQ-Q2B02W
SW1, SW2, SW3, SW4, SW5, SW6: SW_Push; SW_PG1350_reversible
TP1: GND; TestPoint_THTPad_D1.0mm_Drill0.5mm
TP2: Switch 6; TestPoint_THTPad_D1.0mm_Drill0.5mm
TP3: Switch 5; TestPoint_THTPad_D1.0mm_Drill0.5mm
TP4: Switch 4; TestPoint_THTPad_D1.0mm_Drill0.5mm
TP5: Switch 3; TestPoint_THTPad_D1.0mm_Drill0.5mm
TP6: Switch 2; TestPoint_THTPad_D1.0mm_Drill0.5mm
TP7: Switch 1; TestPoint_THTPad_D1.0mm_Drill0.5mm
TP8: Button 2; TestPoint_THTPad_D1.0mm_Drill0.5mm
TP9: Button 1; TestPoint_THTPad_D1.0mm_Drill0.5mm
TP10: LED_IN; TestPoint_THTPad_D1.0mm_Drill0.5mm
TP11: +5V; TestPoint_THTPad_D1.0mm_Drill0.5mm

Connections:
+5V: C2.1, C3.1, C4.1, C5.1, C6.1, C7.1, C8.1, C9.1, C10.1, C11.1, C12.1, C13.1, C14.1, C15.1, C16.1, C17.1, C18.1, C19.1, C20.1, C21.1, D1.1 (VDD), D2.1 (VDD), D3.1 (VDD), D4.1 (VDD), D5.1 (VDD), D6.1 (VDD), D7.1 (VDD), D8.1 (VDD), D9.1 (VDD), D10.1 (VDD), D11.1 (VDD), D12.1 (VDD), D13.1 (VDD), D14.1 (VDD), D15.1 (VDD), D16.1 (VDD), D17.1 (VDD), D18.1 (VDD), D19.1 (VDD), D20.1 (VDD), TP11.1
/Button 1: S1.B, S1.B', TP9.1
/Button 2: S2.B, S2.B', TP8.1
/LED_IN: D1.4 (DIN), TP10.1
/Switch 1: SW1.2, TP7.1
/Switch 2: SW2.2, TP6.1
/Switch 3: SW3.2, TP5.1
/Switch 4: SW4.2, TP4.1
/Switch 5: SW5.2, TP3.1
/Switch 6: SW6.2, TP2.1
GND: C2.2, C3.2, C4.2, C5.2, C6.2, C7.2, C8.2, C9.2, C10.2, C11.2, C12.2, C13.2, C14.2, C15.2, C16.2, C17.2, C18.2, C19.2, C20.2, C21.2, D1.3 (VSS), D2.3 (VSS), D3.3 (VSS), D4.3 (VSS), D5.3 (VSS), D6.3 (VSS), D7.3 (VSS), D8.3 (VSS), D9.3 (VSS), D10.3 (VSS), D11.3 (VSS), D12.3 (VSS), D13.3 (VSS), D14.3 (VSS), D15.3 (VSS), D16.3 (VSS), D17.3 (VSS), D18.3 (VSS), D19.3 (VSS), D20.3 (VSS), S1.A, S1.A', S2.A, S2.A', SW1.1, SW2.1, SW3.1, SW4.1, SW5.1, SW6.1, TP1.1
unnamed: D1.2 (DOUT), D2.4 (DIN)
unnamed: D2.2 (DOUT), D3.4 (DIN)
unnamed: D3.2 (DOUT), D4.4 (DIN)
unnamed: D4.2 (DOUT), D5.4 (DIN)
unnamed: D5.2 (DOUT), D6.4 (DIN)
unnamed: D6.2 (DOUT), D7.4 (DIN)
unnamed: D7.2 (DOUT), D8.4 (DIN)
unnamed: D8.2 (DOUT), D9.4 (DIN)
unnamed: D9.2 (DOUT), D10.4 (DIN)
unnamed: D10.2 (DOUT), D11.4 (DIN)
unnamed: D11.2 (DOUT), D12.4 (DIN)
unnamed: D12.2 (DOUT), D13.4 (DIN)
unnamed: D13.2 (DOUT), D14.4 (DIN)
unnamed: D14.2 (DOUT), D15.4 (DIN)
unnamed: D15.2 (DOUT), D16.4 (DIN)
unnamed: D16.2 (DOUT), D17.4 (DIN)
unnamed: D17.2 (DOUT), D18.4 (DIN)
unnamed: D18.2 (DOUT), D19.4 (DIN)
unnamed: D19.2 (DOUT), D20.4 (DIN)

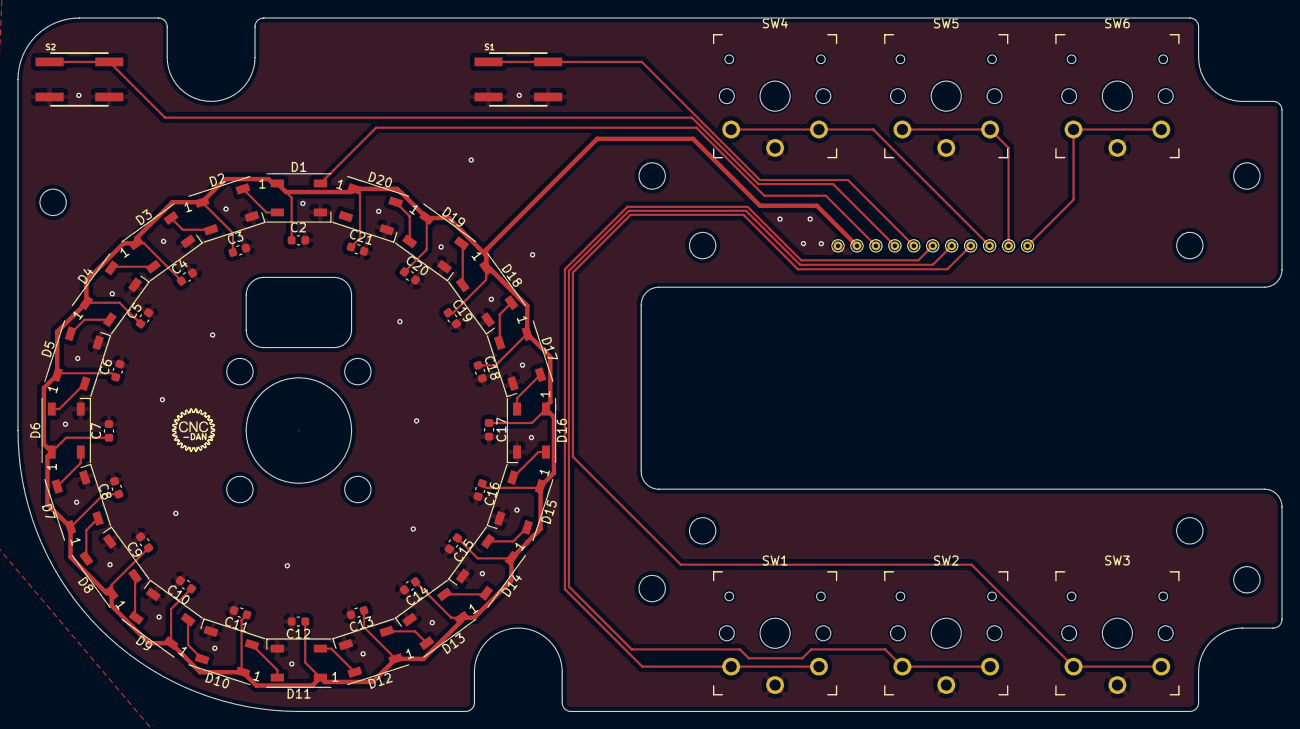
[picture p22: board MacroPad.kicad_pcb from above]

Board: 2 copper layers, 144.0 x 79.0 mm, 59 parts (0 on the bottom side), 30 nets.

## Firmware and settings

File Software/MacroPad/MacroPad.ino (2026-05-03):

#include <Arduino.h>
#include <U8g2lib.h>
#include <SimpleFOC.h>
#include <Adafruit_TinyUSB.h>
#include <SPI.h>
#include <SdFat.h>
// This trick makes your old code and xmlData.ino compatible automatically
#define File FsFile
SdFat SD;
#include <FastLED.h>

const unsigned char SD_Card [] PROGMEM = {
	0xff, 0x01, 0x55, 0x01, 0x55, 0x01, 0xff, 0x01, 0x01, 0x03, 0x2d, 0x02, 0x45, 0x03, 0x49, 0x01, 
	0x2d, 0x03, 0x01, 0x02, 0xfd, 0x02, 0x01, 0x02, 0xff, 0x03
};

#ifdef U8X8_HAVE_HW_I2C
#include <Wire.h>
#endif

#define WHEEL_CLICKY    0
#define WHEEL_TWIST     1
#define WHEEL_MOMENTUM  2

#define KEY_LEFT_CTRL 17

#define NUM_LEDS 20
#define DATA_PIN 15

CRGB leds[NUM_LEDS];

// --- SLEEP TIMER VARIABLES ---
unsigned long lastActivityTime = 0;
const unsigned long SLEEP_TIMEOUT = 300000; // 5 minutes (300,000 ms)
bool isAsleep = false; // <--- ADD THIS LINE

//User Configurable LED Settings
byte primaryColour[3] = {0,50,50}; //Red, Green, Blue
byte secondaryColour[3] = {0,0,0};
int ledBrightness = 100;
int ledSpeed = 50;

//LED Sequence Variables
float redScale;
float greenScale;
float blueScale;
int sequenceStep = 0;
int ledMode = 3;
unsigned long ledTimer;

//LED Halo Variables
int haloCount = 0; //Which is the brightest LED in the sequence

//LED Breath Variables
bool breathIncrease = true;

//LED Bands
bool evenNumber = false;
int loopCounter;

bool debug = false;

//SD Pins
const int _MISO = 4;
const int _MOSI = 3;
const int _CS = 5;
const int _SCK = 2;

bool sdDetected = false;

U8G2_SSD1309_128X64_NONAME0_1_4W_SW_SPI u8g2(U8G2_R0, 28, 22, 6, 7, 8);

BLDCMotor motor = BLDCMotor(7);
BLDCDriver6PWM driver = BLDCDriver6PWM(20, 21, 18,19, 16, 17);

//float target_velocity = 6;
Commander command = Commander(Serial);

Encoder encoder = Encoder(27, 26, 1024);
void doA(){encoder.handleA(); lastActivityTime = millis();}
void doB(){encoder.handleB(); lastActivityTime = millis();}

// angle set point variable
float target_angle = 0; //Radians. 1 Rad = 57.2958 Deg
float new_target_angle;

float target_velocity = 0;
float last_velocity = 0;
float testFactor;

float angle_step = radians(360/40);
float encoderAngle;
float lastEncoderAngle;
bool keyPressed = false;
bool wheelKeyPressed = false;

//PID Values

float Clicky_P;
float Clicky_I;
float Twist_P;
float Twist_I;
float Momentum_P;
float Momentum_I;
float motorP = 0.5;
float motorI = 0;
float motorD = 0;

long timer;
long aceltimer;
long mouseTimer;
float interval;
unsigned long wheelKeyTimer;
unsigned long keyTimer;

long debounceTimer;
bool decelDetected = false;
bool decelerating = false;

int wheelMode = 0;
int lastWheelMode = 0;
bool wheelModeChanged = true;

bool FOC_Ready = false;

#define buttonCount 8 //Number of buttons connected
byte buttonPins[buttonCount] = {9, 1, 0, 12, 11, 10, 13, 14}; //1,2,3,4,5,6
int lastButtonState[buttonCount];

//Eeprom Memory
int activeProfile = 0;
//int activePage = 1;

uint8_t icon1[24][3]; //Used to store Icon 1 Data
uint8_t icon2[24][3]; //Used to store Icon 2 Data
uint8_t icon3[24][3]; //Used to store Icon 3 Data
uint8_t icon4[24][3]; //Used to store Icon 4 Data
uint8_t icon5[24][3]; //Used to store Icon 5 Data
uint8_t icon6[24][3]; //Used to store Icon 6 Data

// ---- Profile data ----
#define maxProfileNameLength 32
#define maxProfiles 256
char profileName[maxProfileNameLength];
char profileNames[maxProfileNameLength][maxProfiles];
char buttonLabel[6][32];
unsigned long profileChangeTimer;
bool profilePlusStarted = false;
bool profileMinusStarted = false;
bool profileSelectMenu = false;

uint8_t wheelAction;
uint8_t macroAction[6][3];   // decimal values
uint16_t macroDelay[6][3];
float targetAngle;

// ---- Global ----
uint16_t totalProfiles = 0;

File root;

uint8_t const desc_keyboard_report[] =
{
  TUD_HID_REPORT_DESC_KEYBOARD()
};

uint8_t const desc_mouse_report[] =
{
  TUD_HID_REPORT_DESC_MOUSE()
};

Adafruit_USBD_HID usb_keyboard(desc_keyboard_report, sizeof(desc_keyboard_report), HID_ITF_PROTOCOL_KEYBOARD, 2, false);
Adafruit_USBD_HID usb_mouse(desc_mouse_report, sizeof(desc_mouse_report), HID_ITF_PROTOCOL_MOUSE, 2, false);


// --- USB FLASH DRIVE LOGIC ---
Adafruit_USBD_MSC usb_msc;
volatile bool disk_mode_active = false;

int32_t msc_read_cb (uint32_t lba, void* buffer, uint32_t bufsize) {
  bool rc;
#if SD_FAT_VERSION >= 20000 // Automatically handles the vocabulary difference!
  rc = SD.card()->readSectors(lba, (uint8_t*) buffer, bufsize/512);
#else
  rc = SD.card()->readBlocks(lba, (uint8_t*) buffer, bufsize/512);
#endif
  return rc ? bufsize : -1;
}

int32_t msc_write_cb (uint32_t lba, uint8_t* buffer, uint32_t bufsize) {
  bool rc;
#if SD_FAT_VERSION >= 20000
  rc = SD.card()->writeSectors(lba, (uint8_t*) buffer, bufsize/512);
#else
  rc = SD.card()->writeBlocks(lba, (uint8_t*) buffer, bufsize/512);
#endif
  return rc ? bufsize : -1;
}

void msc_flush_cb (void) {
  SD.card()->syncDevice();
}
// -----------------------------



void managePowerState() {
  // Sleep if USB suspends OR if the 5-minute timer runs out
  bool shouldSleep = TinyUSBDevice.suspended() || (millis() - lastActivityTime > SLEEP_TIMEOUT);

  if (shouldSleep) {
    if (!isAsleep) {
      u8g2.setPowerSave(1); // Turn off screen
      usb_keyboard.keyboardRelease(0); // Release all keys
      fill_solid(leds, NUM_LEDS, CRGB::Black); // Turn off LEDs
      FastLED.show();
      isAsleep = true; // <--- Set global flag
    }
  } else {
    if (isAsleep) {
      u8g2.setPowerSave(0); // Wake screen
      fill_solid(leds, NUM_LEDS, CRGB(primaryColour[0], primaryColour[1], primaryColour[2])); 
      FastLED.show();
      isAsleep = false; // <--- Clear global flag
    }
  }
}

void setup() { // Core 0
  // --- THE BOOT BOUNCER ---
  pinMode(11, INPUT_PULLUP);
  pinMode(9, INPUT_PULLUP);
  delay(50); 

  if (digitalRead(11) == LOW) {
    disk_mode_active = true;

    // 1. TEMPORARILY UNPLUG FROM WINDOWS
    TinyUSBDevice.detach();
    delay(200); // Give Windows time to register the disconnect

    // 2. SET CORRECT HARDWARE SPI PINS FOR SD CARD
    SPI.setRX(_MISO); 
    SPI.setTX(_MOSI); 
    SPI.setSCK(_SCK);

    // 3. INITIALIZE DISPLAY
    u8g2.begin();
    u8g2.firstPage();
    do {
      u8g2.setFont(u8g2_font_5x7_tf);
      u8g2.drawStr(0, 15, "USB DRIVE MODE");
      u8g2.drawStr(0, 30, "Mounting SD...");
    } while ( u8g2.nextPage() );

    // 4. MOUNT SD CARD BEFORE STARTING USB MSC
    if (SD.begin(_CS, SD_SCK_MHZ(40))) {
      
      // Setup the Flash Drive parameters now that SD is ready
      usb_msc.setID("Pico", "SD Card", "1.0");
      usb_msc.setReadWriteCallback(msc_read_cb, msc_write_cb, msc_flush_cb);
      usb_msc.setCapacity(SD.card()->sectorCount(), 512);
      usb_msc.setUnitReady(true);
      usb_msc.begin(); 

      // 5. RE-PLUG INTO WINDOWS
      TinyUSBDevice.attach();

      u8g2.firstPage();
      do {
        u8g2.setFont(u8g2_font_5x7_tf);
        u8g2.drawStr(0, 10, "USB DRIVE ACTIVE");
        u8g2.drawStr(0, 25, "1. Eject on PC");
        u8g2.drawStr(0, 35, "2. Press Button 1");
        u8g2.drawStr(0, 45, "   to Reboot");
      } while ( u8g2.nextPage() );

    } else {
      // Re-attach even on fail so the port isn't left completely dead
      TinyUSBDevice.attach(); 
      
      u8g2.firstPage();
      do {
        u8g2.setFont(u8g2_font_5x7_tf);
        u8g2.drawStr(0, 15, "SD MOUNT FAILED!");
        u8g2.drawStr(0, 30, "Check Card");
      } while ( u8g2.nextPage() );
    }

    return; // Stay in USB mode, bypass normal boot
  }
  // --- END BOOT BOUNCER ---


  driver.voltage_power_supply = 5;
  driver.voltage_limit = 5;
  driver.init();

  encoder.init();
  encoder.enableInterrupts(doA, doB);
  motor.linkSensor(&encoder);

  driver.voltage_power_supply = 5;
  driver.init();

  motor.linkDriver(&driver);
  motor.voltage_sensor_align = 3;

  motor.PID_velocity.D = 0;

  motor.voltage_limit = 3;

  motor.PID_velocity.output_ramp = 1000;
  motor.LPF_velocity.Tf = 0.025f;//0.01f;
  motor.P_angle.P = 20;
  motor.velocity_limit = 4;

  motor.init();
  motor.initFOC();

  Serial.begin(115200);
  if(debug){
    while(!Serial){}
  }
  Serial.println("Motor ready!");
  FOC_Ready = true;
}

void setup1(){ //core 1
  delay(200); // Give Core 0 a tiny head start to check the button
  
  if(disk_mode_active) return; // If flash drive mode is on, SHUT DOWN this core entirely.

  // --- NORMAL MACRO PAD MODE ---
  usb_keyboard.begin();
  usb_mouse.begin();
  FastLED.addLeds<WS2812, DATA_PIN, GRB>(leds, NUM_LEDS);

  SPI.setRX(_MISO);
  SPI.setTX(_MOSI);
  SPI.setSCK(_SCK);

  initialiseSD();
  loadSettings("/config.xml");
  calculateColourMultiplier();

  u8g2.begin();
  for(int i = 0; i < buttonCount; i++){
    pinMode(buttonPins[i], INPUT_PULLUP);
  }
}

void buttonRead(){ //Read button inputs and set state arrays.
for (int i = 0; i < buttonCount; i++){
    int input = !digitalRead(buttonPins[i]);
    if (input != lastButtonState[i]){
      lastButtonState[i] = input;
      
      lastActivityTime = millis(); // <--- WAKES UP THE DEVICE ON BUTTON PRESS
    }
  }
  if(sdDetected && !profileSelectMenu){
    for(int i = 0; i < 6; i++){
      if(lastButtonState[i]){
        macroOutput(i);
        keyPressed = true;
        keyTimer = millis();
      }
    }
    if(lastButtonState[6]){ //Next Profile
      if(!profilePlusStarted){
        profilePlusStarted = true;
        profileChangeTimer = millis();
      }
      if(profilePlusStarted && profileChangeTimer + 100 < millis()){
        profileSelectMenu = true;
        profileChangeTimer = millis();
      }
    } else {
      if(profilePlusStarted){
        if(activeProfile < totalProfiles - 1){
          activeProfile++;
          loadProfile("/config.xml", activeProfile);
          calculateColourMultiplier();
          storeLastProfile();
          Serial.print("Stored last profile = ");
          Serial.println(activeProfile);
          loadButtonIcons();
          delay(100);
        }
      }
    }
    if(lastButtonState[7]){ //Previous Profile
      if(!profileMinusStarted){
        profileMinusStarted = true;
        profileChangeTimer = millis();
      } else if(profileMinusStarted && profileChangeTimer + 100 < millis()){
        profileSelectMenu = true;
        profileChangeTimer = millis();
        //delay(500);
        //Serial.println("Trigger Menu");
      }
    } else {
      if(profileMinusStarted){
        if(activeProfile > 0 ){
          activeProfile--;
          loadProfile("/config.xml", activeProfile);
          calculateColourMultiplier();
          storeLastProfile();
          Serial.print("Stored last profile = ");
          Serial.println(activeProfile);
          loadButtonIcons();
          delay(100);
        }
      }
    }
    if(!lastButtonState[7] && !lastButtonState[6]){
      profileMinusStarted = false;
      profilePlusStarted = false;
    }
      
    if(keyPressed && keyTimer + 50 < millis()){
      usb_keyboard.keyboardRelease(0);
      keyPressed = false;
    }
  } else if(!sdDetected && !profileSelectMenu){
    if(lastButtonState[4]){
      initialiseSD();
      delay(100);
    }
  } else {
    if(profileChangeTimer + 500 < millis()){
      if(lastButtonState[7] || lastButtonState[6]){
        profileSelectMenu = false;
        profileMinusStarted = false;
        profilePlusStarted = false;
        loadProfile("/config.xml", activeProfile);
        calculateColourMultiplier();
        storeLastProfile();
        Serial.print("Stored last profile = ");
        Serial.println(activeProfile);
        loadButtonIcons();
        delay(200);
      }
    }
  }
}

void initialiseSD(){
SD.end(); //Attempt to close any previous SD sessions

  if (!SD.begin(_CS)) {
    Serial.println("initialization failed!");
    return;
  } else {
    sdDetected = true;
    Serial.println("SD Initialised!");
  }

  totalProfiles = countProfiles("/config.xml");
  if(debug){
    Serial.print("Profiles found: ");
    Serial.println(totalProfiles);
  }

  activeProfile = readLastProfile();
  Serial.print("Active Profile = ");
  Serial.println(activeProfile);

  loadProfile("/config.xml", activeProfile);
  calculateColourMultiplier();
  loadButtonIcons();
}

void loop() {
  if (disk_mode_active) { 
    tud_task(); // Keep the USB traffic flowing!
    
    // Check if Button 1 (Pin 9) is pressed to exit Flash Drive Mode
    if (digitalRead(9) == LOW) {
      delay(100); // Quick debounce
rp2040.reboot(); // The correct RP2040-specific restart command!
    }
    
    return; // Freeze the motors
  }

 
  motor.loopFOC();
  // ... rest of the original code ...

  if(lastWheelMode != wheelMode){
    wheelModeChanged = true;
  }
  lastWheelMode = wheelMode;

  if(!profileSelectMenu){
    if(wheelMode == 0){
      notchyWheel();
    } else if(wheelMode == 1){
      twistScroll();
    } else if(wheelMode == 2){
      freeSpinning();
    }
  } else {
    notchyWheel();
  }
}

void macroOutput(int button){
  uint8_t keycode[6] = { 0 };
  int modifier = 0;
        
  for(int i = 0; i < 3; i++){
    delay(macroDelay[button][i]);
    if(macroAction[button][i] != 0){
      keycode[0] = convertKeycode(macroAction[button][i]);
      if(checkModifiers(macroAction[button][i]) != 0){
        modifier = checkModifiers(macroAction[button][i]);
        Serial.println("Modifier Detected");
      } else {
        usb_keyboard.keyboardReport(0, modifier, keycode);
      }
    }
  }
}

void loop1() {

  
if (disk_mode_active) return; // Freeze the OLED and Buttons completely

managePowerState(); // <--- Check power state every loop

  u8g2.firstPage();
  // ... rest of the original code ...

  u8g2.firstPage();
  buttonRead();
 if(ledTimer + ledSpeed < millis() && !isAsleep){ // <--- Add && !isAsleep
    if(ledMode == 0){
      haloLED();
    } else if(ledMode == 1){
      breathLED();
    } else if(ledMode == 2){
      ledBand();
    } else if(ledMode == 3){
      rainbowLED();
    } else if(ledMode == 4){
      solidLED();
    } else {
      offLED();
    }
    ledTimer = millis();
  }
  
  do {
    if(sdDetected){
      if(!profileSelectMenu){
        drawGrid();
        drawActiveProfile();
      } else {
        drawProfileMenu();
      }

      encoderAngle = encoder.getAngle();

      if(wheelMode == 2){
        if(abs(lastEncoderAngle - encoderAngle) > 0.1){
          wheelActionCheck();
          usb_mouse.mouseScroll(0, (lastEncoderAngle - encoderAngle) * 10, 0);
          lastEncoderAngle = encoderAngle;
        } else {
          cancelWheelAction();
        }
      }
    } else {
      u8g2.drawXBMP(59, 10, 10, 13, SD_Card);
      u8g2.setFont(u8g2_font_5x7_tf);
      u8g2.drawStr(17, 36, "No SD Card Detected!");
      u8g2.drawStr(53, 60, "Retry");
    }

  } while ( u8g2.nextPage() );
}

bool storeLastProfile(){
  Serial.println("--- ATTEMPTING TO SAVE PROFILE ---");
  
  // 1. Try to remove the file (using a safe 8.3 filename)
  bool removed = SD.remove("/last.txt");
  if(removed) {
    Serial.println("Success: Old last.txt deleted.");
  } else {
    Serial.println("Notice: Could not delete last.txt (might not exist yet).");
  }

  // 2. Try to create the new file
  File file = SD.open("/last.txt", FILE_WRITE);
  if (file) {
    file.print(activeProfile);
    file.close();
    Serial.println("Success: New profile number saved to last.txt!");
    return true;
  } else {
    Serial.println("FATAL ERROR: SD.open failed. Cannot write to card!");
    return false;
  }
}

int readLastProfile(){
  // Look for the new safe filename
  File file = SD.open("/last.txt"); 
  
  // If it doesn't exist yet, fallback to the old one so it doesn't break
  if (!file){
    file = SD.open("/lastProfile"); 
    if (!file) return 0; // If neither exist, return profile 0
  }

  int savedProfile = file.parseInt(); 
  file.close(); 
  return (uint8_t)savedProfile; 
}

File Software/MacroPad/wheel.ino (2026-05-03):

void twistScroll(){
  if(wheelModeChanged){
    targetAngle = encoder.getAngle();
    motor.controller = MotionControlType::angle;
    motor.PID_velocity.I = Twist_I; //0.2;
    Serial.print("Set I = ");
    Serial.println(Twist_I);
    motor.PID_velocity.P = Twist_P; //0.65f;
    Serial.print("Set P = ");
    Serial.println(Twist_P);
    motor.enable();
    wheelModeChanged = false;
  }

  encoderAngle = encoder.getAngle();

  motor.move(targetAngle);

  interval = 50 / abs(encoderAngle - targetAngle);

  if(abs(encoderAngle - targetAngle) > 0.2){ 
    if(mouseTimer + interval < millis()){
      wheelActionCheck();
      if(encoderAngle > targetAngle){
        usb_mouse.mouseScroll(0, -1, 0);
      } else {
        usb_mouse.mouseScroll(0, 1, 0);
      }
      mouseTimer = millis();
    } else {
      cancelWheelAction();
    }
  }
}
/*void twistScroll(){ //Uncommment for consant movement instead of twist mode
  if(wheelModeChanged){
    //targetAngle = encoder.getAngle();
    motor.controller = MotionControlType::velocity;
    motor.enable();
    wheelModeChanged = false;
  }

  motor.move(1);

}*/

void notchyWheel(){
  int scroll;

  if(wheelModeChanged){
    motor.controller = MotionControlType::angle;
    motor.PID_velocity.I = Clicky_I;//0;
    Serial.print("Set I = ");
    Serial.println(Clicky_I);
    motor.PID_velocity.P = Clicky_P;//0.5f;
    Serial.print("Set P = ");
    Serial.println(Clicky_P);
    motor.enable();
    wheelModeChanged = false;
  }


  motor.move(target_angle);
  encoderAngle = encoder.getAngle(); //6

  new_target_angle = round(encoderAngle / angle_step) * angle_step;

  if(new_target_angle != target_angle){
    wheelActionCheck();
    scroll = round((target_angle - new_target_angle) / angle_step);
    if(!profileSelectMenu){
      usb_mouse.mouseScroll(0, scroll, 0);
    } else {
      if(scroll < 0){
        if(activeProfile < totalProfiles - 1){
          activeProfile++;
        }
      } else {
        if(activeProfile > 0){
          activeProfile--;
        }
      }
    }
    target_angle = new_target_angle;
    motor.move(target_angle);
  } else {
    cancelWheelAction();
  }
}

void wheelActionCheck(){
  wheelKeyTimer = millis();
  if(wheelAction != 0 && !wheelKeyPressed){
    int modifier = checkModifiers(wheelAction);
    uint8_t keycode[6] = { 0 };
    if(modifier != 0){
      usb_keyboard.keyboardReport(0, modifier, 0);
    } else {
      keycode[0] = convertKeycode(wheelAction);
      usb_keyboard.keyboardReport(0, 0, keycode);
    }
    wheelKeyPressed = true;
    delay(10); //Slight delay to ensure keyboard report has been sent before mouse move
  }
}

void cancelWheelAction(){
  if(wheelKeyPressed && wheelKeyTimer + 100 < millis()){
    usb_keyboard.keyboardReport(0, 0, 0);
    wheelKeyPressed = false;
  }
}

void freeSpinning(){
  if(wheelModeChanged){
    motor.controller = MotionControlType::velocity;
    motor.PID_velocity.I = Momentum_I; //0;
    motor.PID_velocity.P = Momentum_P; //0.3f;
    wheelModeChanged = false;
  }

  //motor.disable();

  float vel = encoder.getVelocity(); //Read current encoder velocity

  if(!decelerating){
    if(abs(last_velocity - vel) > 0.1){//Detected deceleration
      if(decelDetected){
        if(debounceTimer + 100 < millis()){
          last_velocity = vel;
          if(vel > 0){
            target_velocity = vel + 2; //Set current velocity as target
          } else {
            target_velocity = vel - 2; //Set current velocity as target
          }
          if(abs(target_velocity) > 6){
            motor.enable();
          }
          debounceTimer = millis();
        }
      } else {
        decelDetected = true;
        debounceTimer = millis();
      }
    } else {
      decelDetected = false;
      last_velocity = vel;
    }
  }

  if(motor.enabled){
    if(vel > 0.2){ //Moving in the positive direction
      if(aceltimer + 400 < micros()){
        target_velocity -= 0.02;
        aceltimer = micros();
        decelerating = true;
      }
    } else if(vel < -0.2){ //Moving in the negative direction
      if(aceltimer + 400 < micros()){
        target_velocity += 0.02;
        aceltimer = micros();
        decelerating = true;
      }
    } else {
      motor.disable();

      encoderAngle = encoder.getAngle();
      lastEncoderAngle = encoderAngle;

      decelerating = false;
      debounceTimer = millis();
      last_velocity = vel;
      target_velocity = 0;
    }
    motor.move(target_velocity);
  }
}

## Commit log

2026-05-03 Local updates: USB Drive mode, Power Management, and folder reorganization
    [Custom Keycap.STL, Encoder Mount.STL, LED Diffuser Ring.STL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]
2026-05-03 Finalize Haptic Pad v2.0: Updated documentation with high-res media, UI layout overhaul, and hardware assembly tips.
